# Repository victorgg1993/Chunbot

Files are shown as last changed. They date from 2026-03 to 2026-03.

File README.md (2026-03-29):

# 春 Bot

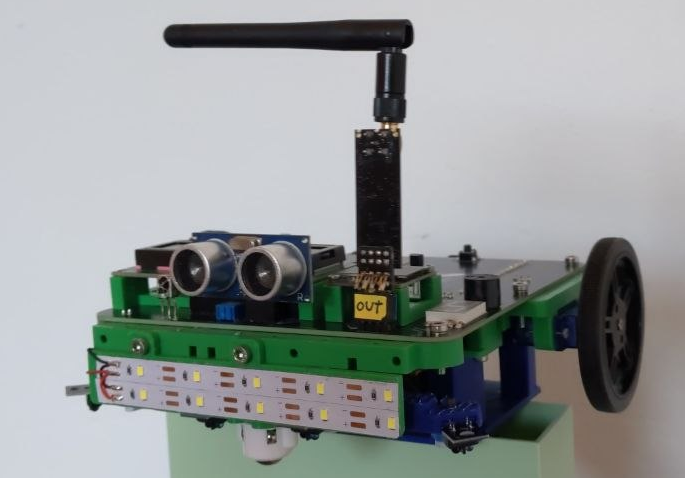
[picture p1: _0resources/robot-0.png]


## Este proyecto tiene dos bloques:

### Mando

- **3D**: modelos 3D del mando
- **Codigo**: Ejemplos de código para el mando
- **PCB**: Diseños de la placa

### Robot

- **3D**: modelos 3D del robot
- **Codigo**: Ejemplos de código para el robot
- **PCB**: Diseños de la placa

## Instalación de dispositivos:

En Linux es necesario añadir los dispositivos en una whitelist en _/etc/udev/rules.d_. Se recomienda seguir la instalación oficial ya que las nuevas versiones de la IDE de Arduino lo gestionan de forma automática.

Link: https://docs.arduino.cc/software/ide-v2/tutorials/getting-started/ide-v2-downloading-and-installing/

---

## Instalación de las librerías:

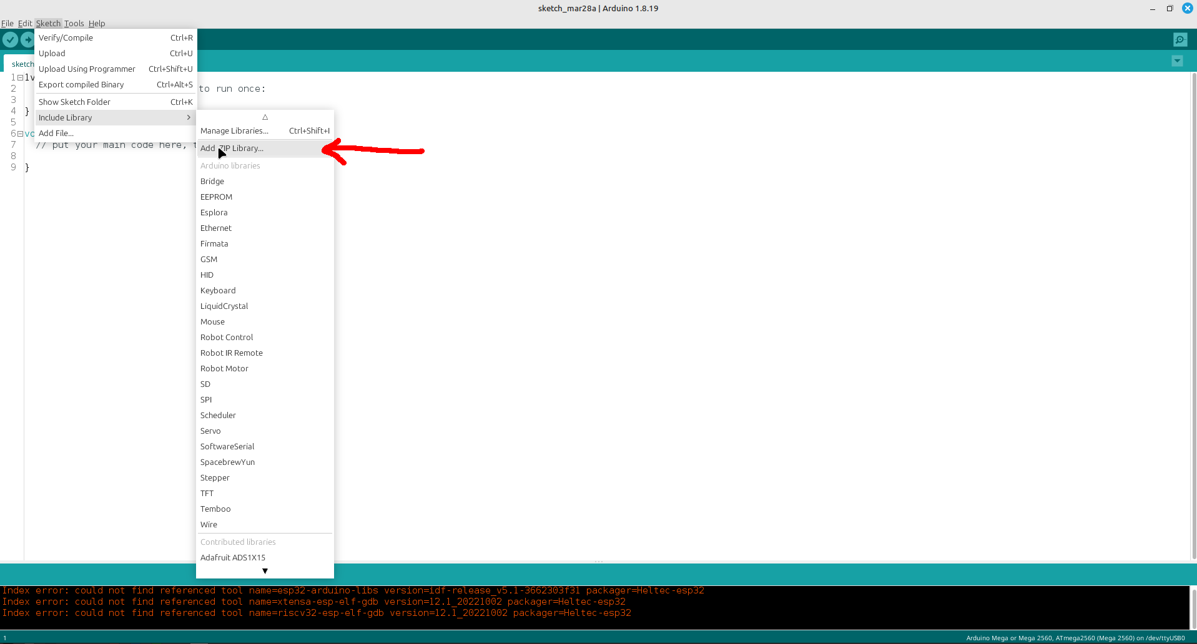
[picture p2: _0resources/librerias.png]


Una vez se abra el menú, cargar las librerías que se encuentran en este proyecto.
La carpeta donde se encuentran las librerías a instalar es "LibreriasArduino".

---

## Elegir microcontrolador:

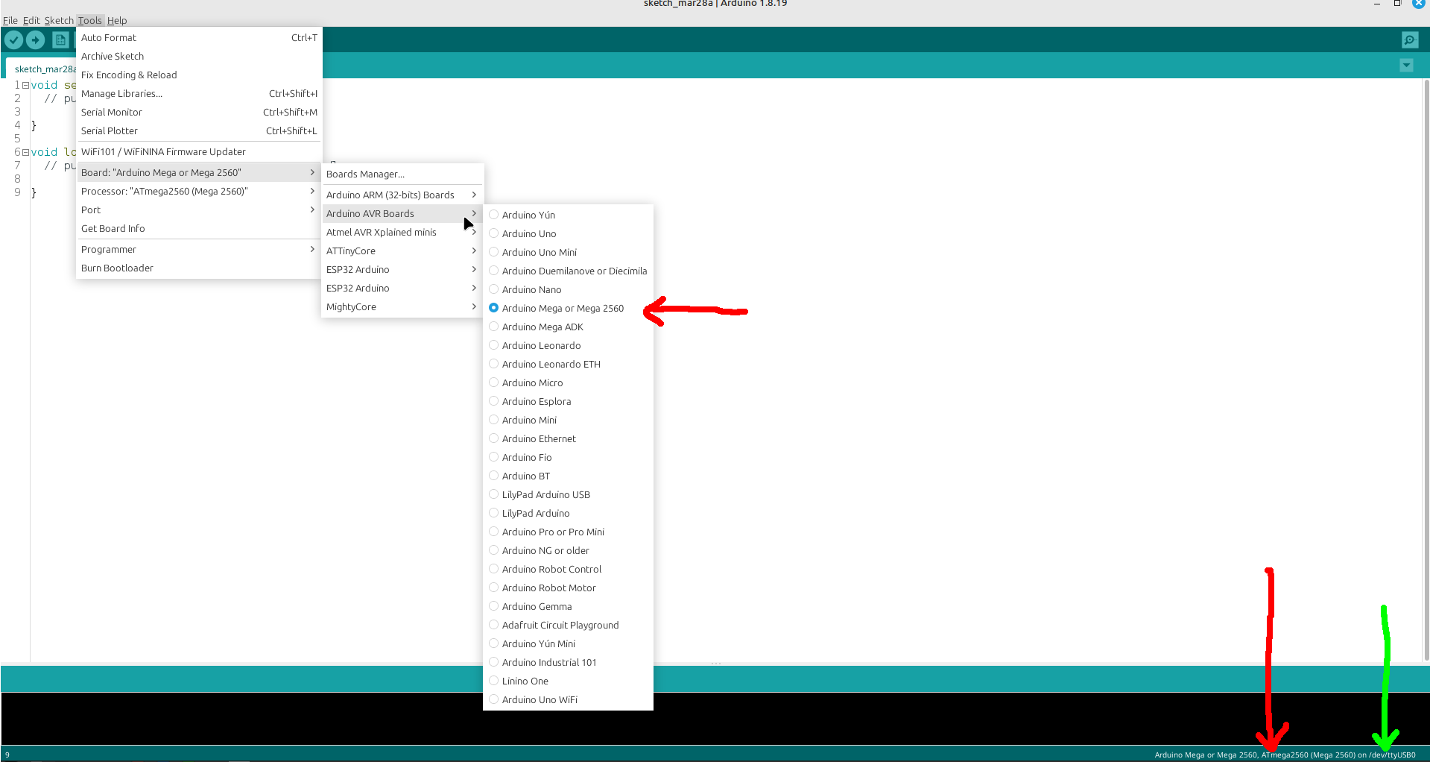
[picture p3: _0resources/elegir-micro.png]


La flecha roja muestra en todo momento qué placa tenemos seleccionada, la verde indica qué puerto USB será usado para programar el microcontrolador.

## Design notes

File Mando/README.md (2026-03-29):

# Mando 春 Bot

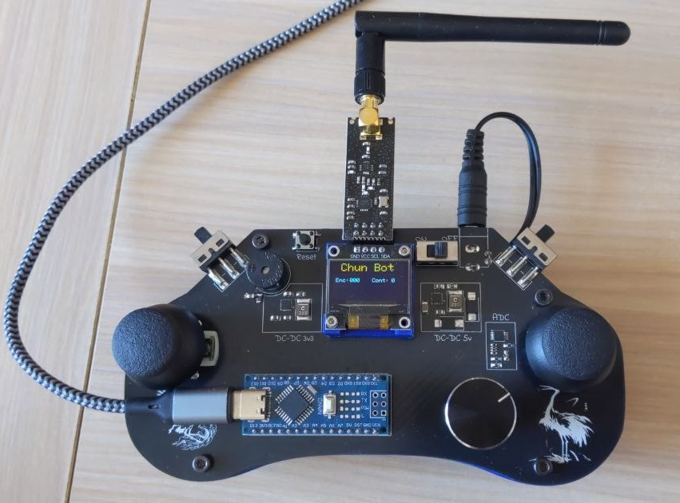
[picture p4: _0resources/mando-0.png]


## Contenido:

- PCB: Diseño de la PCB, tanto esquemáticos como la propia PCB ( Kicad )
- 3D: Modelos 3D ( FreeCAD )
- Codigo: Contiene códigos de ejemplo ( Arduino Nano )

## Pines:

| Uso | Pin | Uso |
| :---: | :-: | :---: |
| Interruptores | D5  | Interruptor lateral derecho |
| Interruptores | D6  | Interruptor lateral izquierdo |
| | | |
| Encoder | D2  | Encoder, pin A. Usa interrupciones |
| Encoder | D3  | Encoder, pin B. Usa interrupciones |
| Encoder | D4  | Pulsador del encoder |
| | | |
| Zumbador | A0  | Pin PWM para el control del zumbador ( buzzer ) |
| | | |
| Joystick | A4  | SDA chip ADC ( analogic to digital converter ) usado para el joystick |
| Joystick | A5  | SCL chip ADC ( analogic to digital converter ) usado para el joystick |
| Joystick | A6  | alert pin del chip ADC ( no implementado ) |
| Joystick | D7  | Pulsador joystick izquierdo |
| Joystick | D8  | Pulsador joystick derecho |
| | | |
| OLED | A4  | SDA, bus I2C de la pantalla OLED. Pin compartido con el joystick |
| OLED | A5  | SCL, bus I2C de la pantalla OLED. Pin compartido con el joystick |
| | | |
| Radio | D13 | Módulo radio NRF24L01, pin SPI SCK |
| Radio | D12 | Módulo radio NRF24L01, pin SPI MISO |
| Radio | D11 | Módulo radio NRF24L01, pin SPI MOSI |
| Radio | D10 | Módulo radio NRF24L01, pin SPI #CNS |
| Radio | D9  | Módulo radio NRF24L01, pin SPI CE |
| | | |

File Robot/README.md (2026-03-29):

# 春 Bot

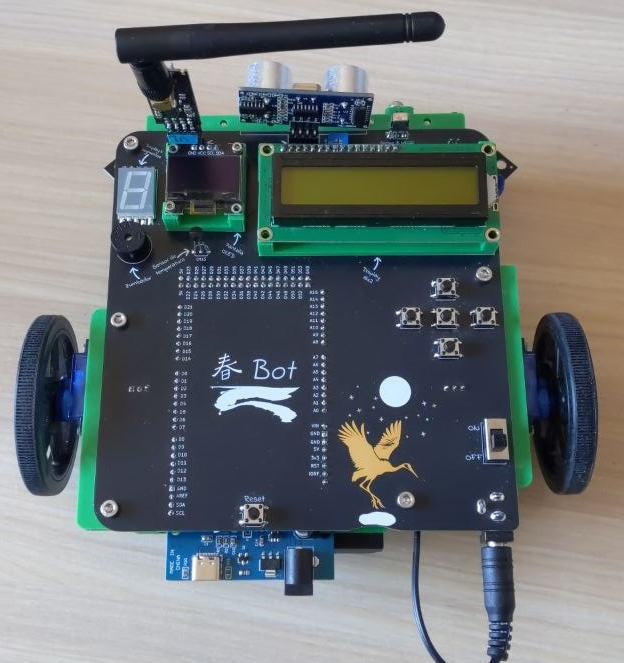
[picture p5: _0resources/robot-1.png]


## Contenido:

- PCB: Diseño de la PCB, tanto esquemáticos como la propia PCB ( Kicad )
- 3D: Modelos 3D ( FreeCAD )
- Codigo: Contiene códigos de ejemplo ( Arduino Mega 2560 )

## Pines:

| Uso | Pin | Uso |
| :---: | :-: | :---: |
| Faros | A14 | Controla un mosfet que enciende y apaga los focos frontales |
| | | |
| Temperatura  | A15 | Sensor de temperatura. Acepta TMP36 y LM35 |
| | | |
|  Pulsadores  | A8  | Pulsador abajo |
|  Pulsadores  | A9  | Pulsador derecha |
|  Pulsadores  | A10 | Pulsador central/ok |
|  Pulsadores  | A11 | Pulsador izquierda |
|  Pulsadores  | A12 | Pulsador arriba |
| | | |
| Radio | D18 | Módulo radio NRF24L01, pin de interrupción. ( no implementado ) |
| Radio | D50 | Módulo radio NRF24L01, pin SPI MISO |
| Radio | D51 | Módulo radio NRF24L01, pin SPI MOSI |
| Radio | D52 | Módulo radio NRF24L01, pin SPI SCK |
| Radio | D53 | Módulo radio NRF24L01, pin SPI #CNS |
| Radio | D43 | Módulo radio NRF24L01, pin SPI CE |
| | | |
| Siguelíneas  | D23 | Sensor izquierdo exterior del seguidor de líneas |
| Siguelíneas  | D41 | Sensor izquierdo interior del seguidor de líneas |
| Siguelíneas  | D42 | Sensor derecho exterior del seguidor de líneas |
| Siguelíneas  | D45 | Sensor derecho interior del seguidor de líneas |
| | | |
| Display16x2  | D33 | Data 4 ( bus de datos ) |
| Display16x2  | D35 | Data 5 ( bus de datos ) |
| Display16x2  | D37 | Data 6 ( bus de datos ) |
| Display16x2  | D39 | Data 7 ( bus de datos ) |
| Display16x2  | D31 | Enable |
| Display16x2  | D29 | RS |
| Display16x2  | D27 | Controla un mosfet que enciende y apaga la luz del display |
| | | |
| Display7seg  | D17 | Segmento A |
| Display7seg  | D25 | Segmento B |
| Display7seg  | D16 | Segmento C |
| Display7seg  | D15 | Segmento D |
| Display7seg  | D14 | Segmento E |
| Display7seg  | D22 | Segmento F |
| Display7seg  | D24 | Segmento G |
| | | |
| OLED | D20 | SDA, bus I2C de la pantalla OLED |
| OLED | D21 | SCL, bus I2C de la pantalla OLED |
| | | |
| Servos | D8  | Servo izquierdo. Usa PWM para su control |
| Servos | D12 | Servo derecho. Usa PWM para su control |
| Servos | D6  | Servo extra 1. Usa PWM para su control |
| Servos | D7  | Servo extra 2. Usa PWM para su control |
| Servos | D9  | Servo extra 3. Usa PWM para su control |
| Servos | D10 | Servo extra 4. Usa PWM para su control |
| Servos | D11 | Servo extra 5. Usa PWM para su control |
| | | |
| Zumbador | D5  | Control vía PWM del zumbador piezoeléctrico |
| | | |
| Mando TV | D4  | Sensor infrarrojo para el mando de TV. Usa el protocolo NEC32 |
| | | |
| Ultrasonidos | D3  | Emite una señal de eco que rebota contra el objeto |
| Ultrasonidos | D2  | Recibe la señal de eco emitida por el otro pin ( usa interrupciones ) |
| | | |

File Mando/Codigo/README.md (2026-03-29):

# Mando 春 Bot

## Ejemplos de código:

- **controlRobot**: Código para controlar el robot vía radiocontrol
- **buzzer**: Suena una melodía por el zumbador
- **encoder**: Imprime por la pantalla OLED el valor del encoder y su pulsador integrado
- **interruptoresLaterales**: Muestra los valores de los interruptores laterales
- **joystick**: Imprime por la pantalla OLED los valores de los joysticks ( eje Y ) y sus pulsadores integrados

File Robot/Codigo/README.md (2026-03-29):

Ejemplos de código:

- **controlRobot**: Código para controlar el robot vía radiocontrol.
- **faros**: Enciende y apaga las luces al pulsar el botón central.
- **display7segmentos**: Incrementa o decrementa el número en función del pulsador derecho o izquierdo.
- **buzzer**: Toca una melodía distinta en función de si se pulsa el botón up, center o down.
- **pulsadores**: muestra el estado de los pulsadores por la pantalla oled.
- **temperatura**: Pinta la temperatura ambiente por el display 16x2. El sensor es el TMP36, aunque aceptaría LM35.
- **ultrasonidos**: Te da la distancia en cm leída del sensor de ultrasonidos por el display 16x2.
- **mandoTV**: Devuelve el código leído del mando de TV por el display 16x2. El número 1 enciende la luz del display, el 0 la apaga.
- **seguidorLineas**: El robot sigue una línea negra sobre fondo blanco ( grosor máximo de la línea, 15mm ).

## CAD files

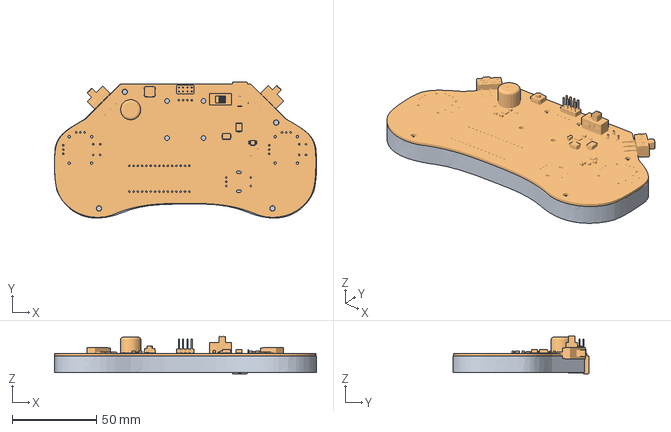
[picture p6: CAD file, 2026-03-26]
Mando/3D/mando.FCStd
155.4 x 80.8 x 22.4 mm
cuerpo
PCB

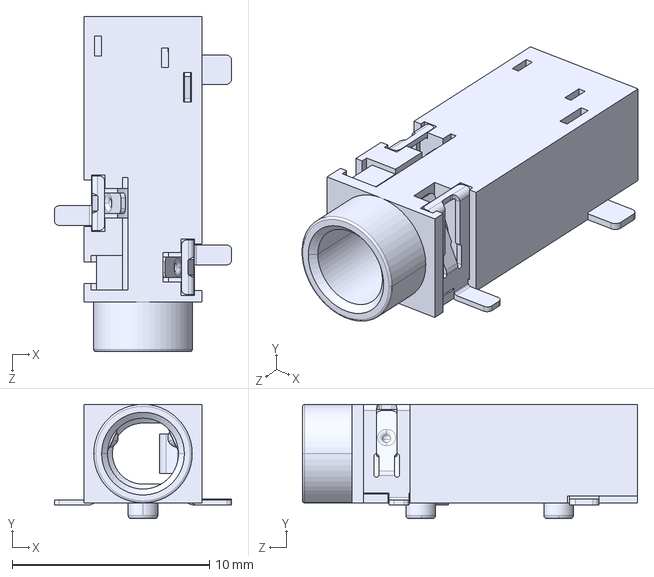
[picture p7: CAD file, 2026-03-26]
Mando/PCB/librerias/3D/SJ-3523-SMT-TR.step
9.00 x 5.80 x 17.0 mm

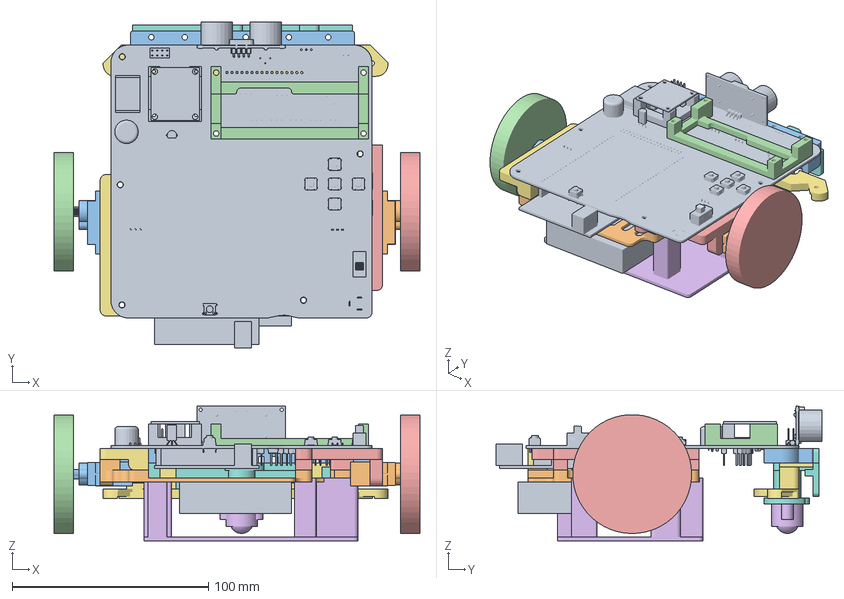
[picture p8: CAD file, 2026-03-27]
Robot/3D/3DChunbot.FCStd
186.3 x 166.0 x 68.6 mm
clip_oled
motor_derecho
motor_izquierdo
rueda_test_izquierdo
rueda_test_derecho
giro-loco
clip_izquierdo_motor
frontal-LED
portapilas
parrilla_pilas
parachoques
clip_16x02
clip_derecho_motor
stand_robot
clip-sensores-ir
base_giro-loco
PCB_ChunBot

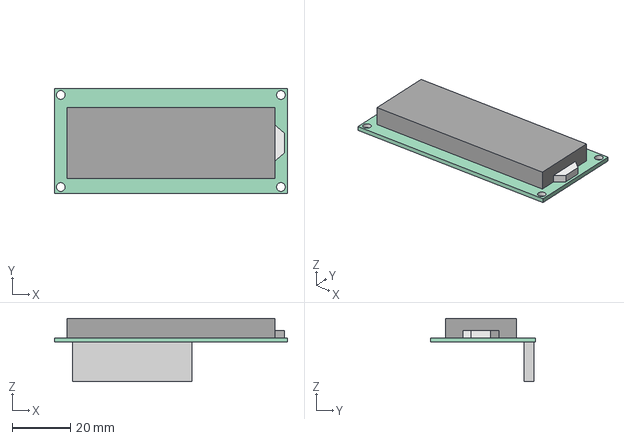
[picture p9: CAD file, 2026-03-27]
Robot/PCB/librerias/3D/display1602.step
80.0 x 36.0 x 21.7 mm

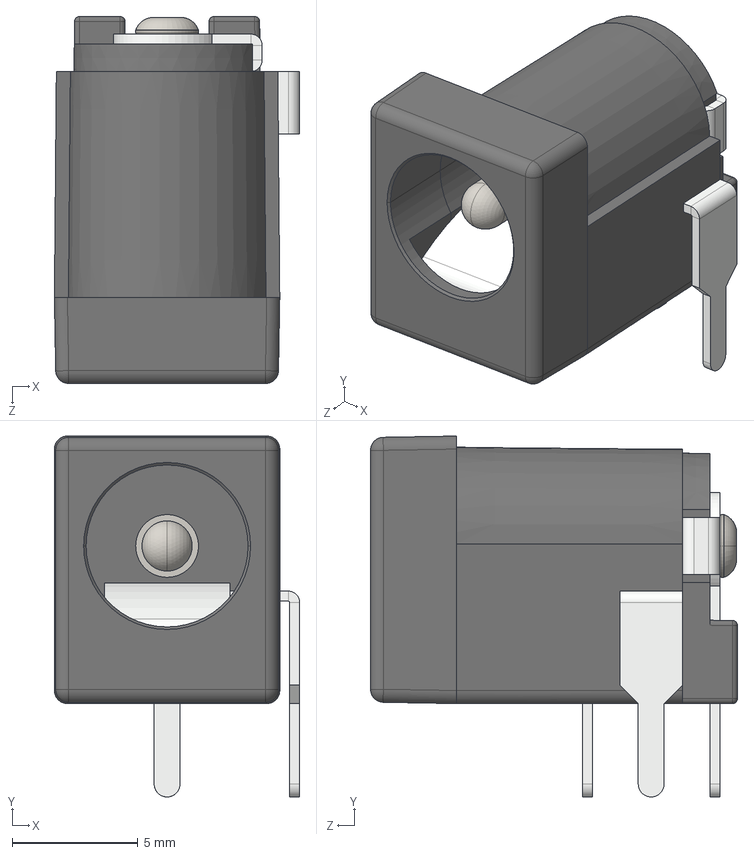
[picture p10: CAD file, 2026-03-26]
Mando/PCB/librerias/3D/PowerJack.STEP
9.77 x 14.4 x 14.6 mm

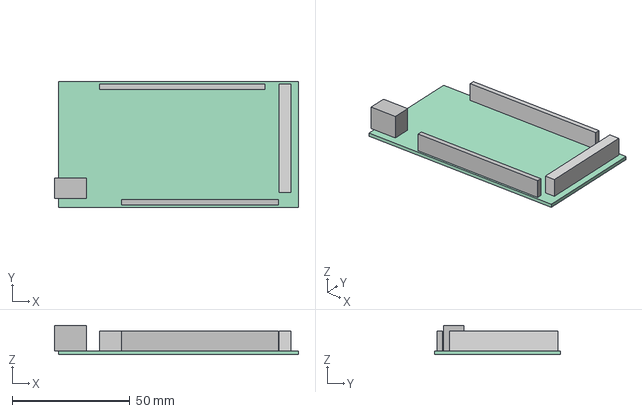
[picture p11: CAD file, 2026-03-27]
Robot/PCB/librerias/3D/Arduino_Mega_2560.step
103.4 x 53.3 x 12.5 mm

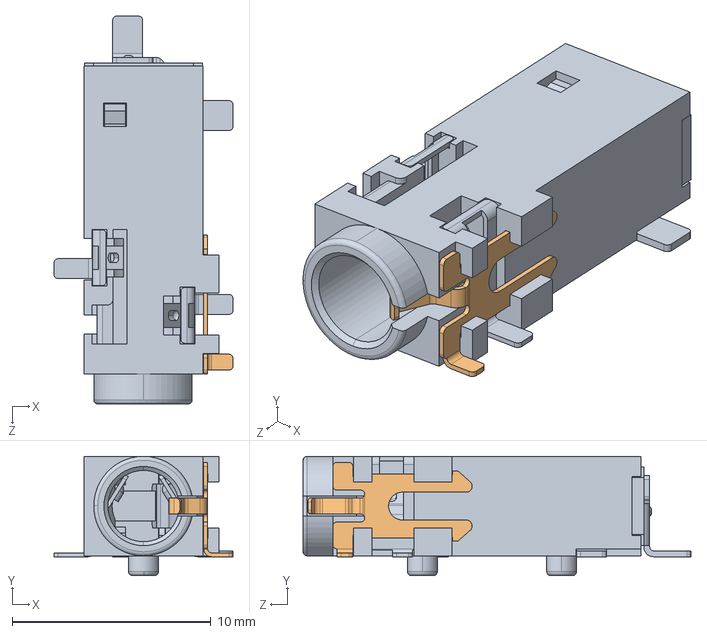
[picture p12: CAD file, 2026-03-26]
Mando/PCB/librerias/3D/SJ-43515TS-SMT-TR.step
9.00 x 6.00 x 19.5 mm

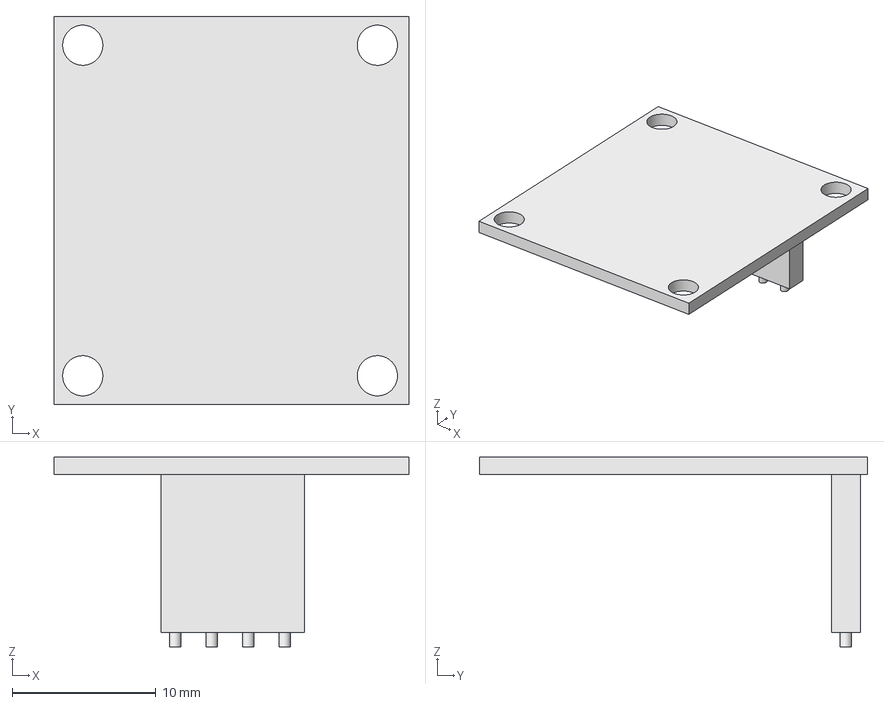
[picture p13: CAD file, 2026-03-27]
Robot/PCB/librerias/3D/oled_096.step
24.7 x 27.0 x 13.2 mm

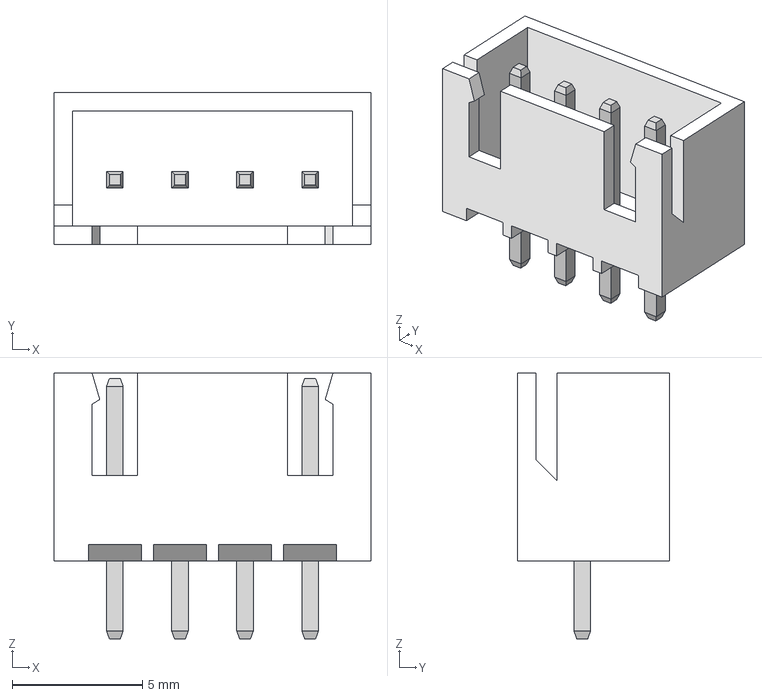
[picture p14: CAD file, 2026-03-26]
Mando/PCB/librerias/3D/JST - XH - Thru - 4Pin - 2.5mm (Genuine).stp
12.2 x 5.84 x 10.2 mm

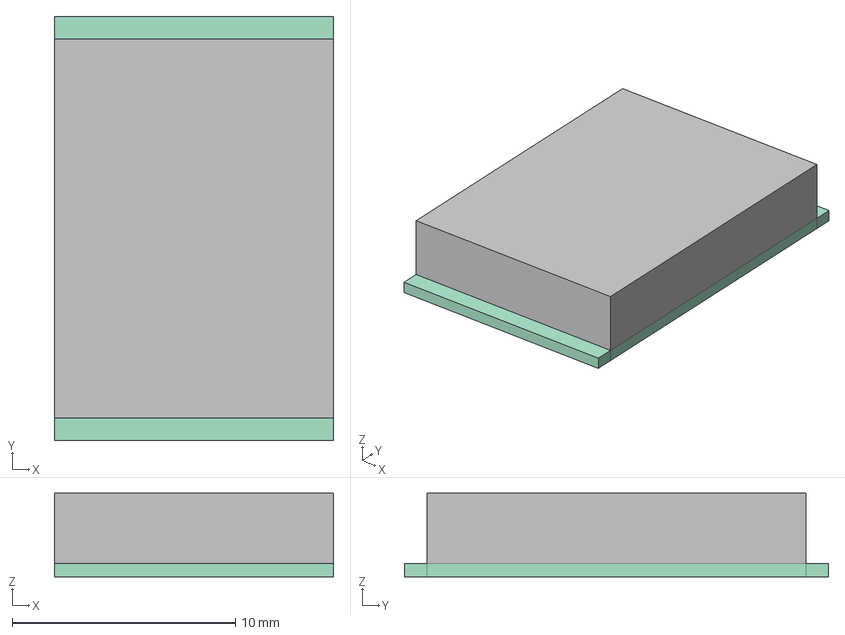
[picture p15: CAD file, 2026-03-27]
Robot/PCB/librerias/3D/7segment.step
12.5 x 19.0 x 3.75 mm

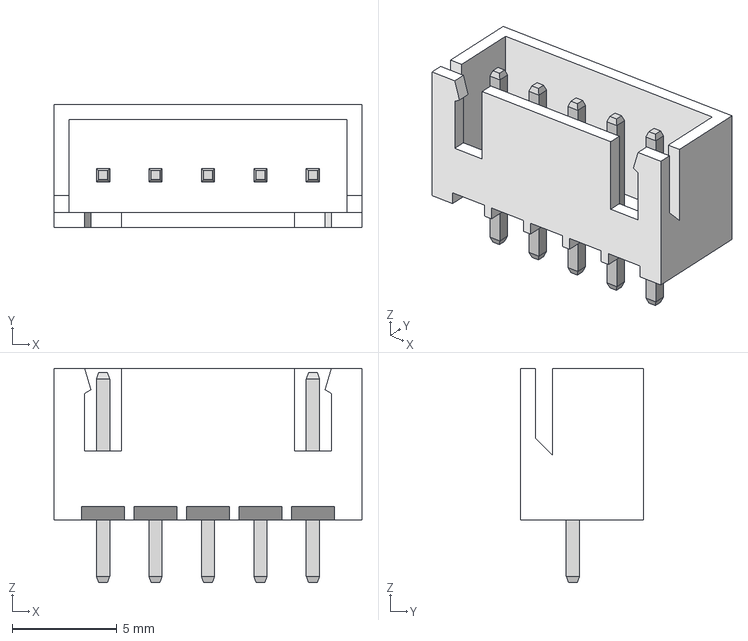
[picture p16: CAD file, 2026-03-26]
Mando/PCB/librerias/3D/JST - XH - Thru - 5Pin - 2.5mm (Genuine).stp
14.7 x 5.84 x 10.2 mm

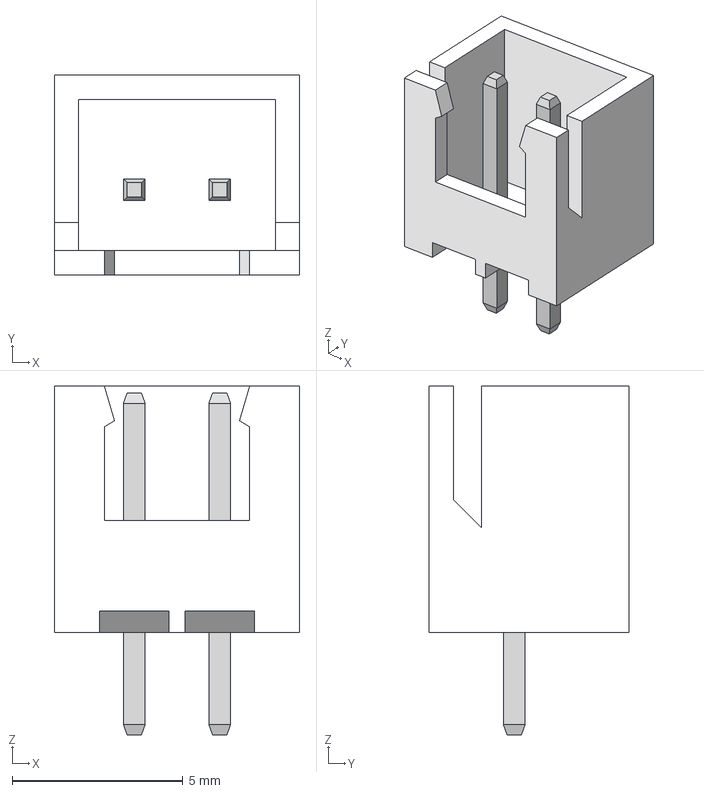
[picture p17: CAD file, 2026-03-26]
Robot/PCB/librerias/3D/JST - XH - Thru - 2Pin - 2.5mm (Genuine).stp
7.17 x 5.84 x 10.2 mm

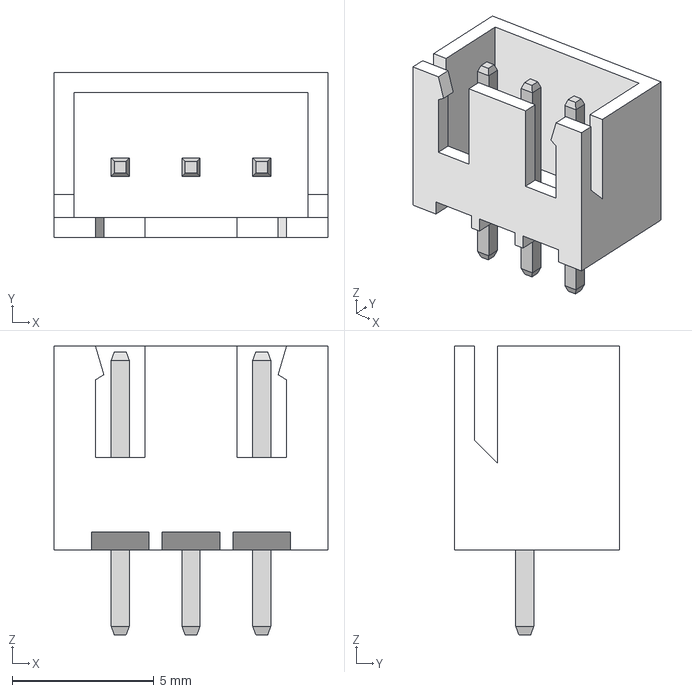
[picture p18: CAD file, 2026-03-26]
Mando/PCB/librerias/3D/JST - XH - Thru - 3Pin - 2.5mm (Genuine).stp
9.67 x 5.84 x 10.2 mm

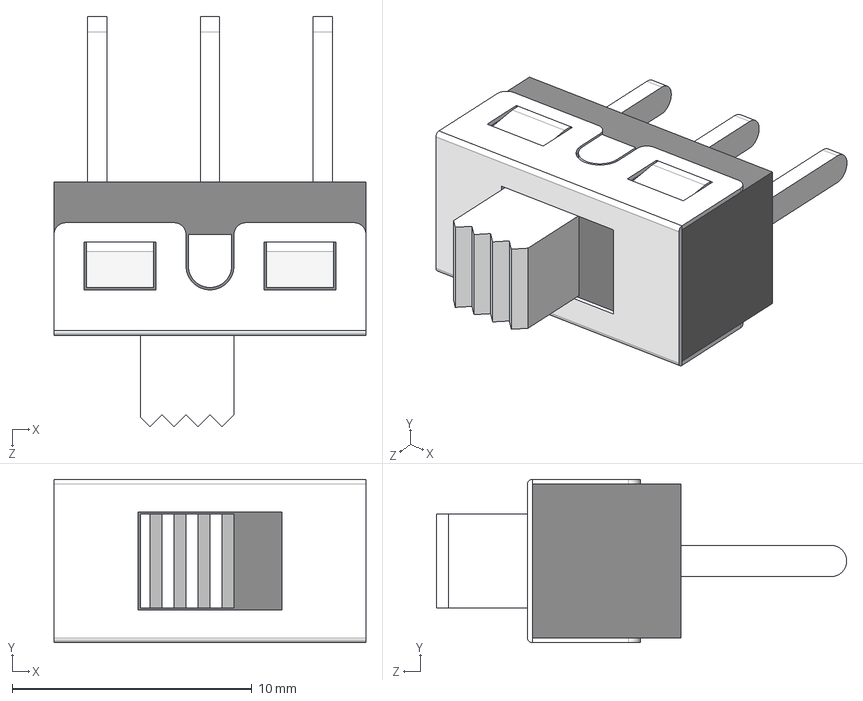
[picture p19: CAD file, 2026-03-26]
Robot/PCB/librerias/3D/SS-12D10L4.STEP
13.0 x 6.80 x 17.1 mm

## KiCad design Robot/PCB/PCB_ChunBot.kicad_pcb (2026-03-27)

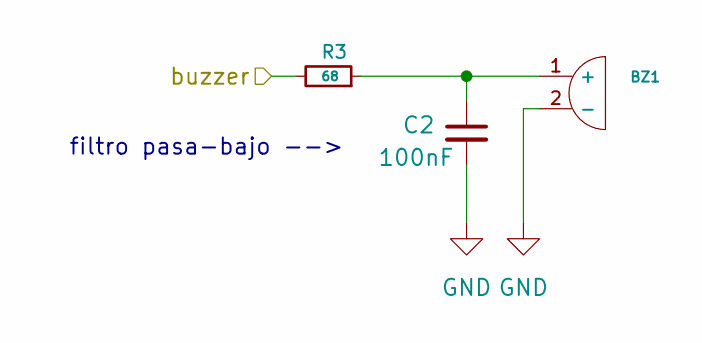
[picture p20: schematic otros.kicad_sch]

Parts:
BZ1: Buzzer_12x9.5RM7.6
C2: 100nF; C_0805_2012Metric_Pad1.18x1.45mm_HandSolder
R3: 68; R_0805_2012Metric

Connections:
GND: BZ1.2 (-), C2.2; also elsewhere on the board
unnamed: BZ1.1 (+), C2.1, R3.1
buzzer: R3.2; also elsewhere on the board

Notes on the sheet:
filtro pasa-bajo -->

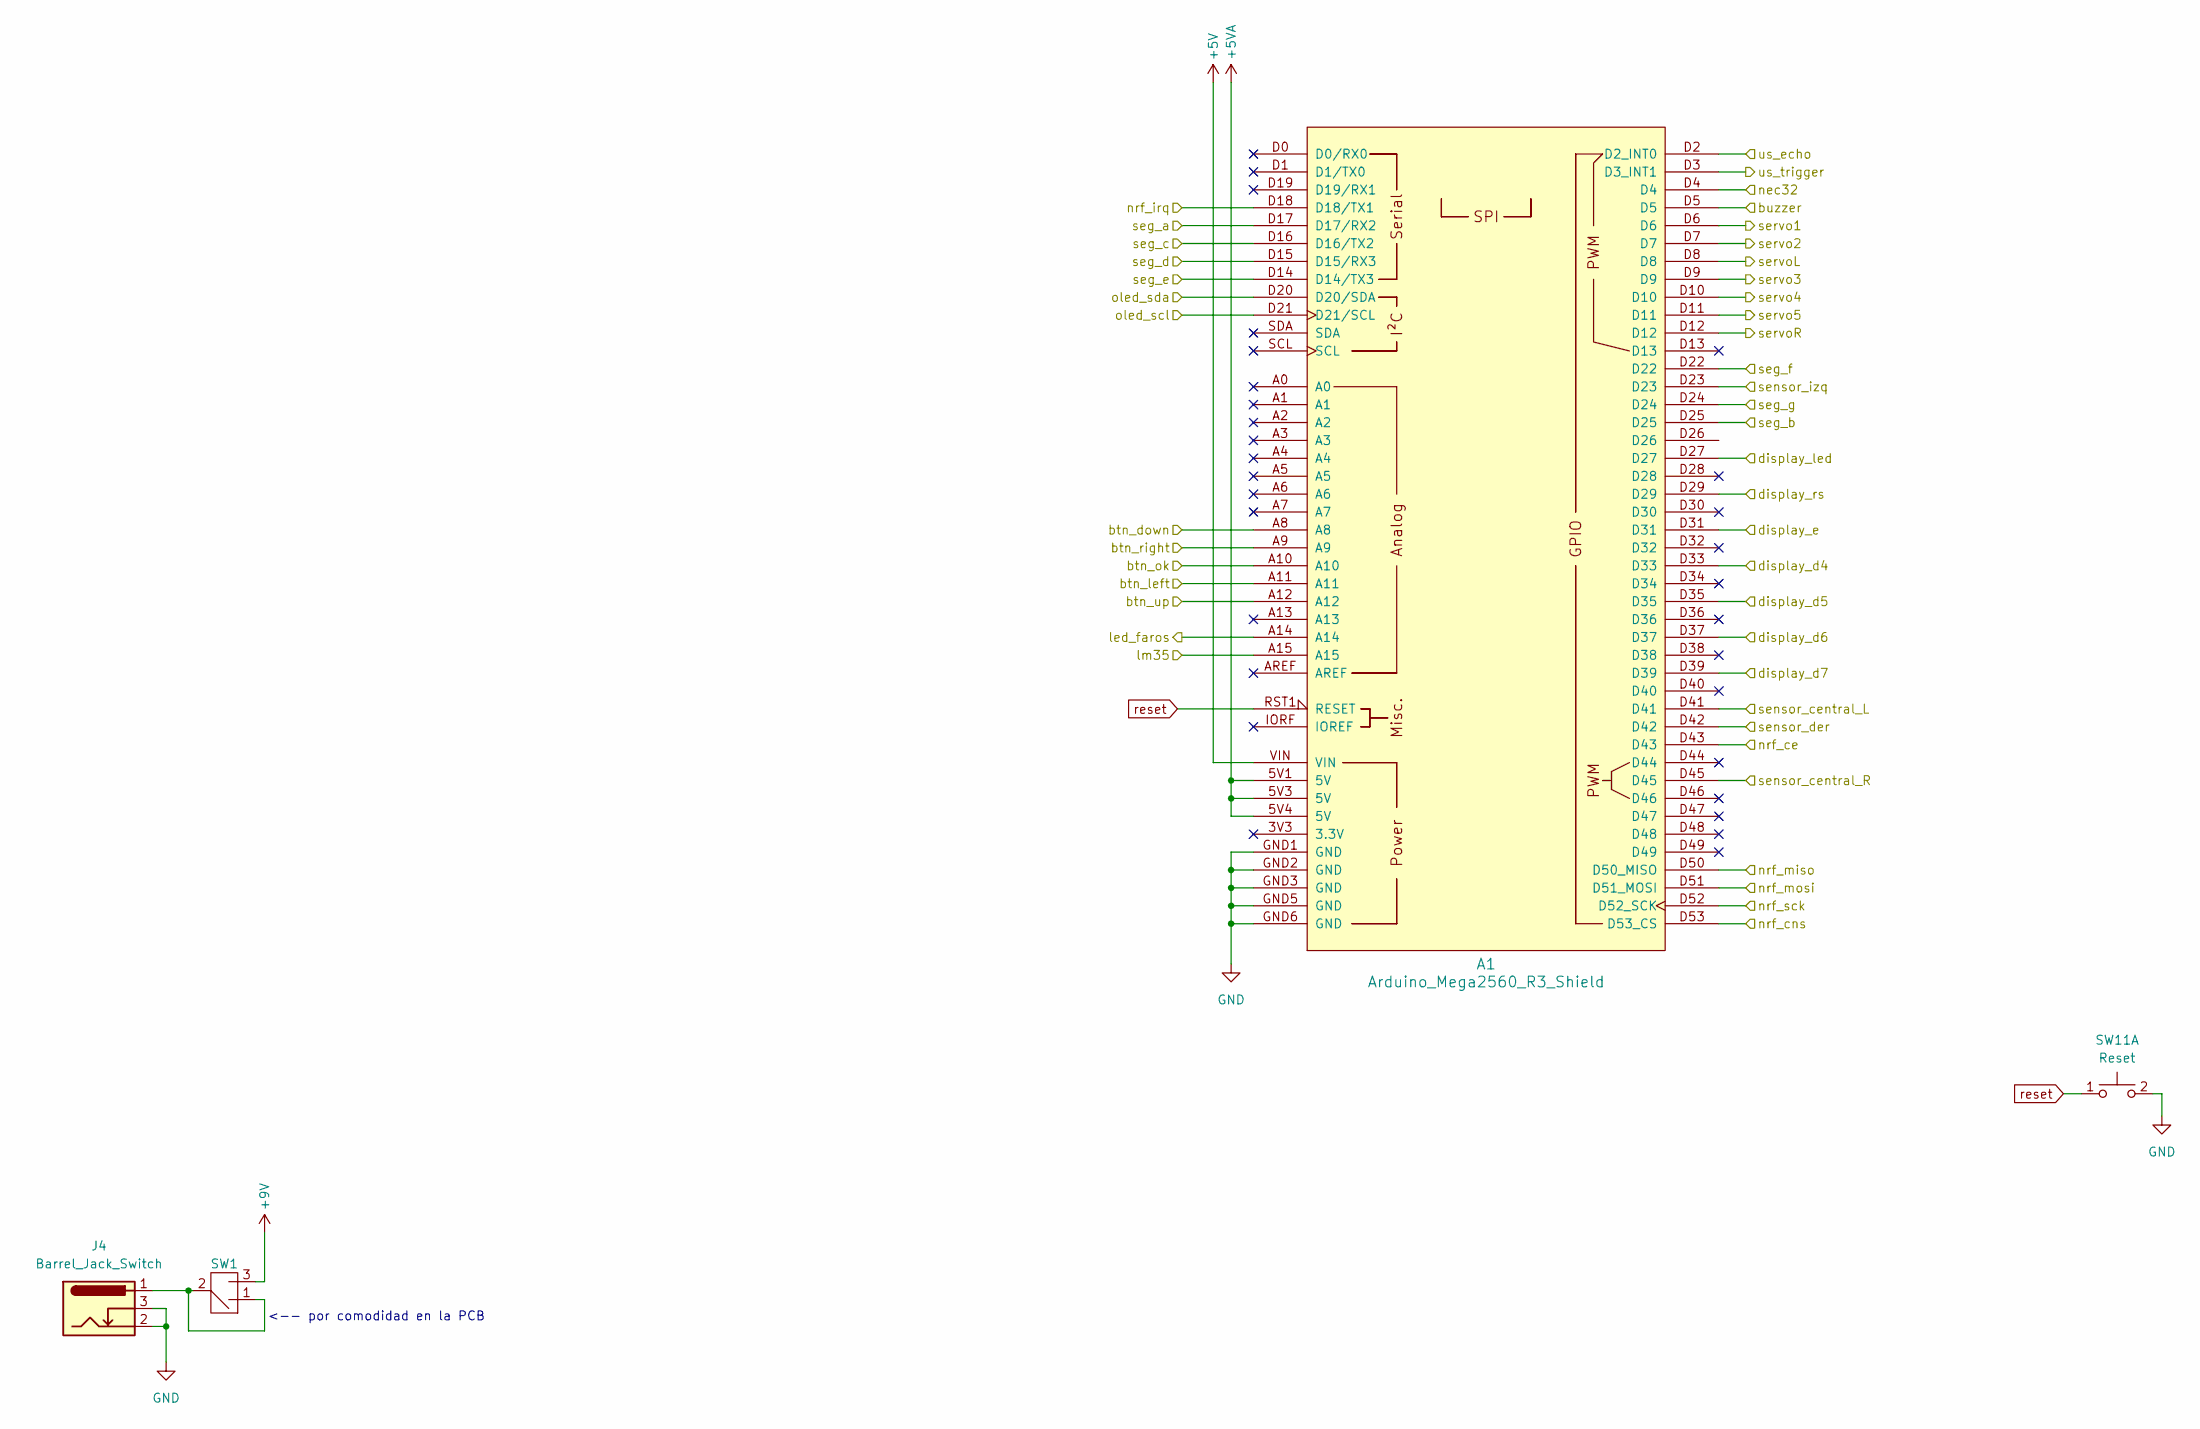
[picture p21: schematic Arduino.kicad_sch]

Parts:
A1: Arduino_Mega2560_R3_Shield
J4: Barrel_Jack_Switch; POWER_JACK_SLOT
SW1: SS12D10
SW11: Reset; SW_PUSH_6mm_H5mm

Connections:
+5V: A1.VIN; also elsewhere on the board
+5VA: A1.5V1 (5V), A1.5V3 (5V), A1.5V4 (5V); also elsewhere on the board
+9V: SW1.3; also elsewhere on the board
GND: A1.GND1 (GND), A1.GND2 (GND), A1.GND3 (GND), A1.GND5 (GND), A1.GND6 (GND), J4.2, J4.3, SW11.2 (D); also elsewhere on the board
unnamed: J4.1, SW1.1, SW1.2
btn_down: A1.A8; also elsewhere on the board
btn_left: A1.A11; also elsewhere on the board
btn_ok: A1.A10; also elsewhere on the board
btn_right: A1.A9; also elsewhere on the board
btn_up: A1.A12; also elsewhere on the board
buzzer: A1.D5; also elsewhere on the board
display_d4: A1.D33; also elsewhere on the board
display_d5: A1.D35; also elsewhere on the board
display_d6: A1.D37; also elsewhere on the board
display_d7: A1.D39; also elsewhere on the board
display_e: A1.D31; also elsewhere on the board
display_led: A1.D27; also elsewhere on the board
display_rs: A1.D29; also elsewhere on the board
led_faro: A1.A14; also elsewhere on the board
lm35: A1.A15; also elsewhere on the board
nec32: A1.D4; also elsewhere on the board
nrf_ce: A1.D43; also elsewhere on the board
nrf_cns: A1.D53 (D53_CS); also elsewhere on the board
nrf_irq: A1.D18 (D18/TX1); also elsewhere on the board
nrf_miso: A1.D50 (D50_MISO); also elsewhere on the board
nrf_mosi: A1.D51 (D51_MOSI); also elsewhere on the board
nrf_sck: A1.D52 (D52_SCK); also elsewhere on the board
oled_scl: A1.D21 (D21/SCL); also elsewhere on the board
oled_sda: A1.D20 (D20/SDA); also elsewhere on the board
reset: A1.RST1 (RESET), SW11.1 (C)
seg_a: A1.D17 (D17/RX2); also elsewhere on the board
seg_b: A1.D25; also elsewhere on the board
seg_c: A1.D16 (D16/TX2); also elsewhere on the board
seg_d: A1.D15 (D15/RX3); also elsewhere on the board
seg_e: A1.D14 (D14/TX3); also elsewhere on the board
seg_f: A1.D22; also elsewhere on the board
seg_g: A1.D24; also elsewhere on the board
sensor_central_L: A1.D41; also elsewhere on the board
sensor_central_R: A1.D45; also elsewhere on the board
sensor_der: A1.D42; also elsewhere on the board
sensor_izq: A1.D23; also elsewhere on the board
servo 1: A1.D6; also elsewhere on the board
servo 2: A1.D7; also elsewhere on the board
servo 3: A1.D9; also elsewhere on the board
servo 4: A1.D10; also elsewhere on the board
servo 5: A1.D11; also elsewhere on the board
servoL: A1.D8; also elsewhere on the board
servoR: A1.D12; also elsewhere on the board
ultrasonidos_echo: A1.D2 (D2_INT0); also elsewhere on the board
ultrasonidos_trigger: A1.D3 (D3_INT1); also elsewhere on the board

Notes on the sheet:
<-- por comodidad en la PCB

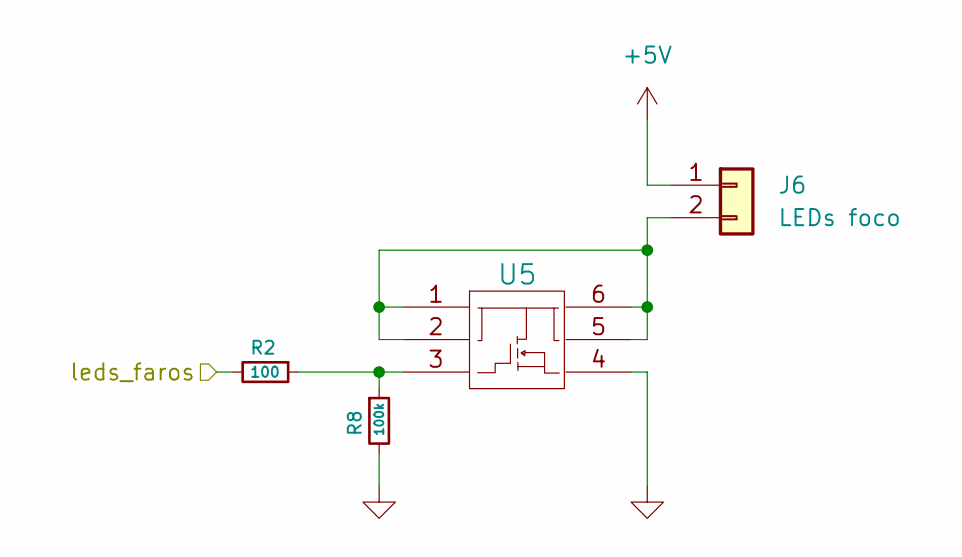
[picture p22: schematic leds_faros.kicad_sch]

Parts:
J6: LEDs foco; XH2.54_2Pin
R2: 100; R_0805_2012Metric
R8: 100k; R_0805_2012Metric
U5: SQ3456BEV; TSOP-6_1.65x3.05mm_P0.95mm

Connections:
+5V: J6.1; also elsewhere on the board
GND: R8.2, U5.4; also elsewhere on the board
unnamed: J6.2, U5.1, U5.2, U5.5, U5.6
unnamed: R2.1, R8.1, U5.3
led_faro: R2.2; also elsewhere on the board

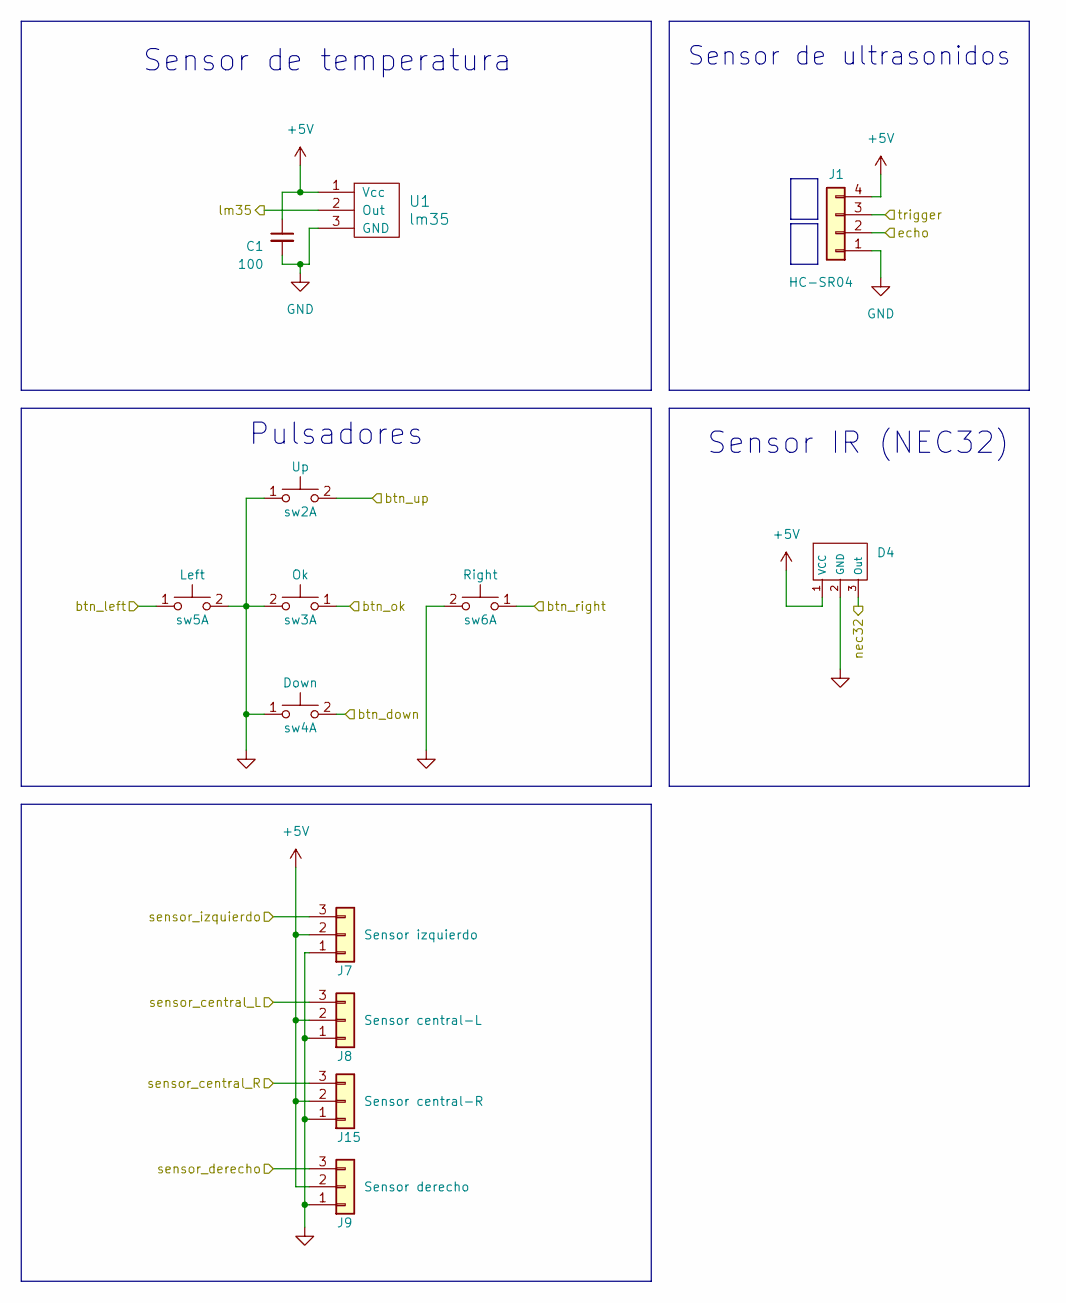
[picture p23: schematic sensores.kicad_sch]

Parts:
C1: 100; C_0805_2012Metric
D4: VS1838
J1: HC-SR04
J7: Sensor izquierdo; PinHeader_1x03_P2.54mm_Vertical
J8: Sensor central-L; PinHeader_1x03_P2.54mm_Vertical
J9: Sensor derecho; PinHeader_1x03_P2.54mm_Vertical
J15: Sensor central-R; PinHeader_1x03_P2.54mm_Vertical
U1: lm35; TO-92L_Inline_Wide
sw2: Up; SW_Push_1P1T_NO_CK_KSC7xxJ
sw3: Ok; SW_Push_1P1T_NO_CK_KSC7xxJ
sw4: Down; SW_Push_1P1T_NO_CK_KSC7xxJ
sw5: Left; SW_Push_1P1T_NO_CK_KSC7xxJ
sw6: Right; SW_Push_1P1T_NO_CK_KSC7xxJ

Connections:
+5V: C1.1, D4.1 (VCC), J1.4, J7.2, J8.2, J9.2, J15.2, U1.1 (Vcc); also elsewhere on the board
GND: C1.2, D4.2 (GND), J1.1, J7.1, J8.1, J9.1, J15.1, U1.3 (GND), sw2.1 (C), sw3.2 (D), sw4.1 (C), sw5.2 (D), sw6.2 (D); also elsewhere on the board
btn_down: sw4.2 (D); also elsewhere on the board
btn_left: sw5.1 (C); also elsewhere on the board
btn_ok: sw3.1 (C); also elsewhere on the board
btn_right: sw6.1 (C); also elsewhere on the board
btn_up: sw2.2 (D); also elsewhere on the board
lm35: U1.2 (Out); also elsewhere on the board
nec32: D4.3 (Out); also elsewhere on the board
sensor_central_L: J8.3; also elsewhere on the board
sensor_central_R: J15.3; also elsewhere on the board
sensor_der: J9.3; also elsewhere on the board
sensor_izq: J7.3; also elsewhere on the board
ultrasonidos_echo: J1.2; also elsewhere on the board
ultrasonidos_trigger: J1.3; also elsewhere on the board

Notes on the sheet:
Sensor IR (NEC32)
Sensor de ultrasonidos
Sensor de temperatura
Pulsadores

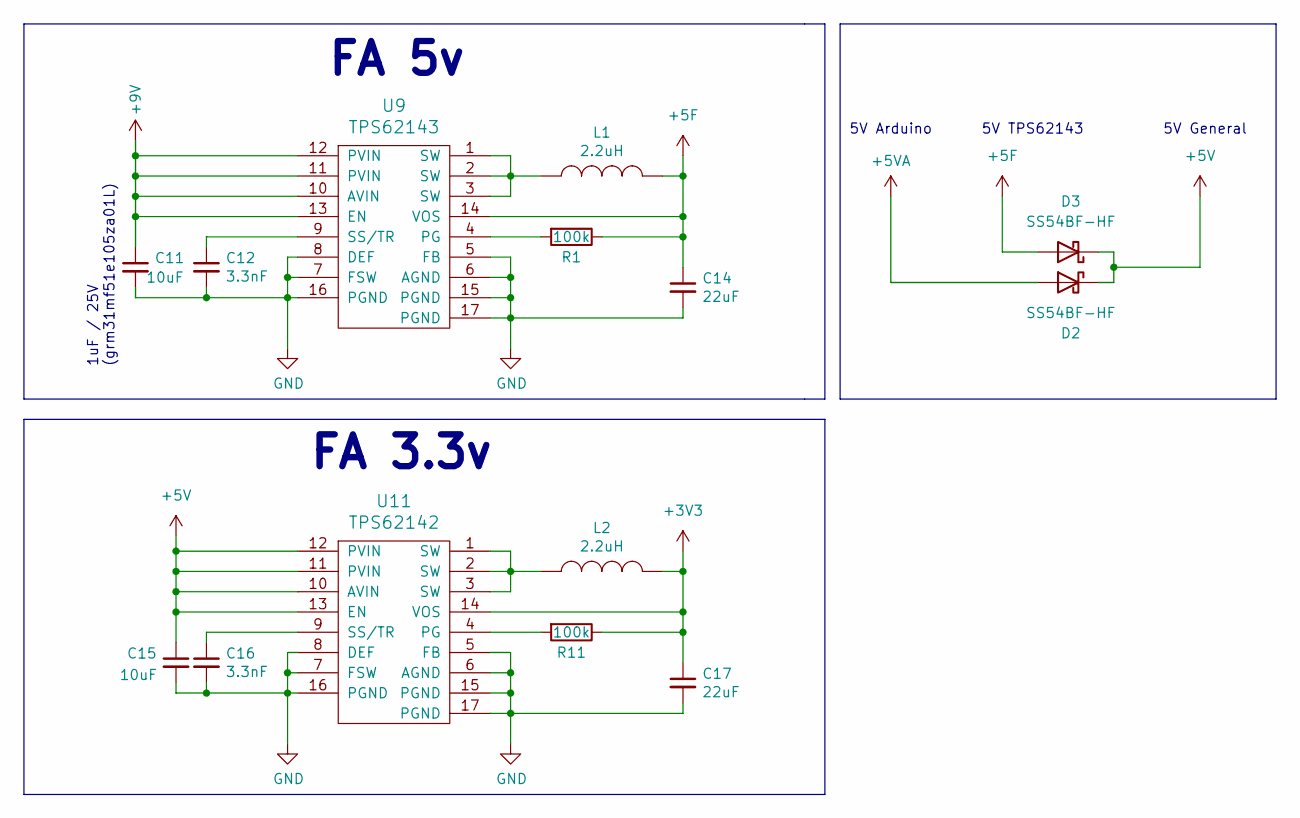
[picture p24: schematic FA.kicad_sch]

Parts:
C11: 10uF; C_1206_3216Metric_Pad1.33x1.80mm_HandSolder
C12, C16: 3.3nF; C_0805_2012Metric_Pad1.18x1.45mm_HandSolder
C14, C17: 22uF; C_0805_2012Metric_Pad1.18x1.45mm_HandSolder
C15: 10uF; C_0805_2012Metric_Pad1.18x1.45mm_HandSolder
D2, D3: SS54BF-HF; D_SMB_Handsoldering
L1, L2: 2.2uH; L_Taiyo-Yuden_NR-50xx_HandSoldering
R1, R11: 100k; R_0805_2012Metric_Pad1.20x1.40mm_HandSolder
U9: TPS62143; QFN-16-1EP_3x3mm_P0.5mm_EP1.7x1.7mm
U11: TPS62142; QFN-16-1EP_3x3mm_P0.5mm_EP1.7x1.7mm

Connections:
+3V3: C17.1, L2.2, R11.1, U11.14 (VOS); also elsewhere on the board
+5F: C14.1, D3.2 (A), L1.2, R1.1, U9.14 (VOS)
+5V: C15.1, D2.1 (K), D3.1 (K), U11.10 (AVIN), U11.11 (PVIN), U11.12 (PVIN), U11.13 (EN); also elsewhere on the board
+5VA: D2.2 (A); also elsewhere on the board
+9V: C11.1, U9.10 (AVIN), U9.11 (PVIN), U9.12 (PVIN), U9.13 (EN); also elsewhere on the board
GND: C11.2, C12.2, C14.2, C15.2, C16.2, C17.2, U9.5 (FB), U9.6 (AGND), U9.7 (FSW), U9.8 (DEF), U9.15 (PGND), U9.16 (PGND), U9.17 (PGND), U11.5 (FB), U11.6 (AGND), U11.7 (FSW), U11.8 (DEF), U11.15 (PGND), U11.16 (PGND), U11.17 (PGND); also elsewhere on the board
unnamed: L1.1, U9.1 (SW), U9.2 (SW), U9.3 (SW)
unnamed: L2.1, U11.1 (SW), U11.2 (SW), U11.3 (SW)
unnamed: R1.2, U9.4 (PG)
unnamed: C12.1, U9.9 (SS/TR)
unnamed: R11.2, U11.4 (PG)
unnamed: C16.1, U11.9 (SS/TR)

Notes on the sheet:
5V General
5V TPS62143
FA 5v
1uF / 25V (grm31mf51e105za01L)
5V Arduino
FA 3.3v

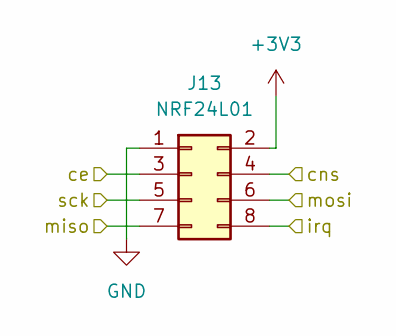
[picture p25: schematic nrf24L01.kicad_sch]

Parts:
J13: NRF24L01; PinHeader_2x04_P2.54mm_Vertical

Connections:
+3V3: J13.2; also elsewhere on the board
GND: J13.1; also elsewhere on the board
nrf_ce: J13.3; also elsewhere on the board
nrf_cns: J13.4; also elsewhere on the board
nrf_irq: J13.8; also elsewhere on the board
nrf_miso: J13.7; also elsewhere on the board
nrf_mosi: J13.6; also elsewhere on the board
nrf_sck: J13.5; also elsewhere on the board

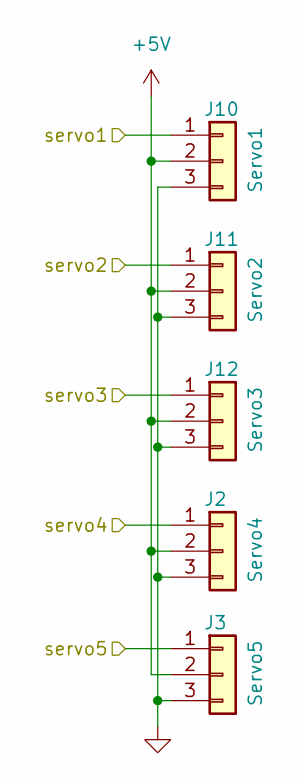
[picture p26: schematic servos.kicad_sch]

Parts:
J2: Servo4; PinHeader_1x03_P2.54mm_Vertical
J3: Servo5; PinHeader_1x03_P2.54mm_Vertical
J10: Servo1; PinHeader_1x03_P2.54mm_Vertical
J11: Servo2; PinHeader_1x03_P2.54mm_Vertical
J12: Servo3; PinHeader_1x03_P2.54mm_Vertical

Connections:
+5V: J2.2, J3.2, J10.2, J11.2, J12.2; also elsewhere on the board
GND: J2.3, J3.3, J10.3, J11.3, J12.3; also elsewhere on the board
servo 1: J10.1; also elsewhere on the board
servo 2: J11.1; also elsewhere on the board
servo 3: J12.1; also elsewhere on the board
servo 4: J2.1; also elsewhere on the board
servo 5: J3.1; also elsewhere on the board

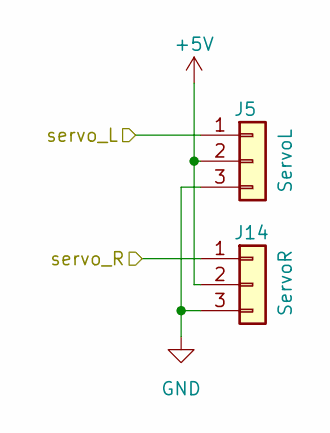
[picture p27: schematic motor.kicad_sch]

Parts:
J5: ServoL; PinHeader_1x03_P2.54mm_Horizontal
J14: ServoR; PinHeader_1x03_P2.54mm_Horizontal

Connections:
+5V: J5.2, J14.2; also elsewhere on the board
GND: J5.3, J14.3; also elsewhere on the board
servoL: J5.1; also elsewhere on the board
servoR: J14.1; also elsewhere on the board

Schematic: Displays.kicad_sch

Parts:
D1: SS511UBWA
DS1: WC1602A
R6: 200; R_0805_2012Metric
R7: 100; R_0805_2012Metric
R9: 100k; R_0805_2012Metric
R10: 150; R_0805_2012Metric
RV1: R_Potentiometer; 3362P
U2: OLED096
U3: SQ3456BEV; TSOP-6_1.65x3.05mm_P0.95mm

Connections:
+5V: DS1.2 (VDD), DS1.15 (LED(+)), RV1.1, U2.2 (VCC); also elsewhere on the board
GND: DS1.1 (VSS), DS1.5 (R/W), R9.2, R10.2, RV1.3, U2.1 (GND), U3.4; also elsewhere on the board
unnamed: D1.3 (K), D1.8 (K), R10.1
unnamed: DS1.16 (LED(-)), R6.1
unnamed: DS1.3 (VO), RV1.2
unnamed: R6.2, U3.1, U3.2, U3.5, U3.6
unnamed: R7.1, R9.1, U3.3
display_d4: DS1.11 (D4); also elsewhere on the board
display_d5: DS1.12 (D5); also elsewhere on the board
display_d6: DS1.13 (D6); also elsewhere on the board
display_d7: DS1.14 (D7); also elsewhere on the board
display_e: DS1.6 (E); also elsewhere on the board
display_led: R7.2; also elsewhere on the board
display_rs: DS1.4 (RS); also elsewhere on the board
oled_scl: U2.3 (SCL); also elsewhere on the board
oled_sda: U2.4 (SDA); also elsewhere on the board
seg_a: D1.7 (a); also elsewhere on the board
seg_b: D1.6 (b); also elsewhere on the board
seg_c: D1.4 (c); also elsewhere on the board
seg_d: D1.2 (d); also elsewhere on the board
seg_e: D1.1 (e); also elsewhere on the board
seg_f: D1.9 (f); also elsewhere on the board
seg_g: D1.10 (g); also elsewhere on the board

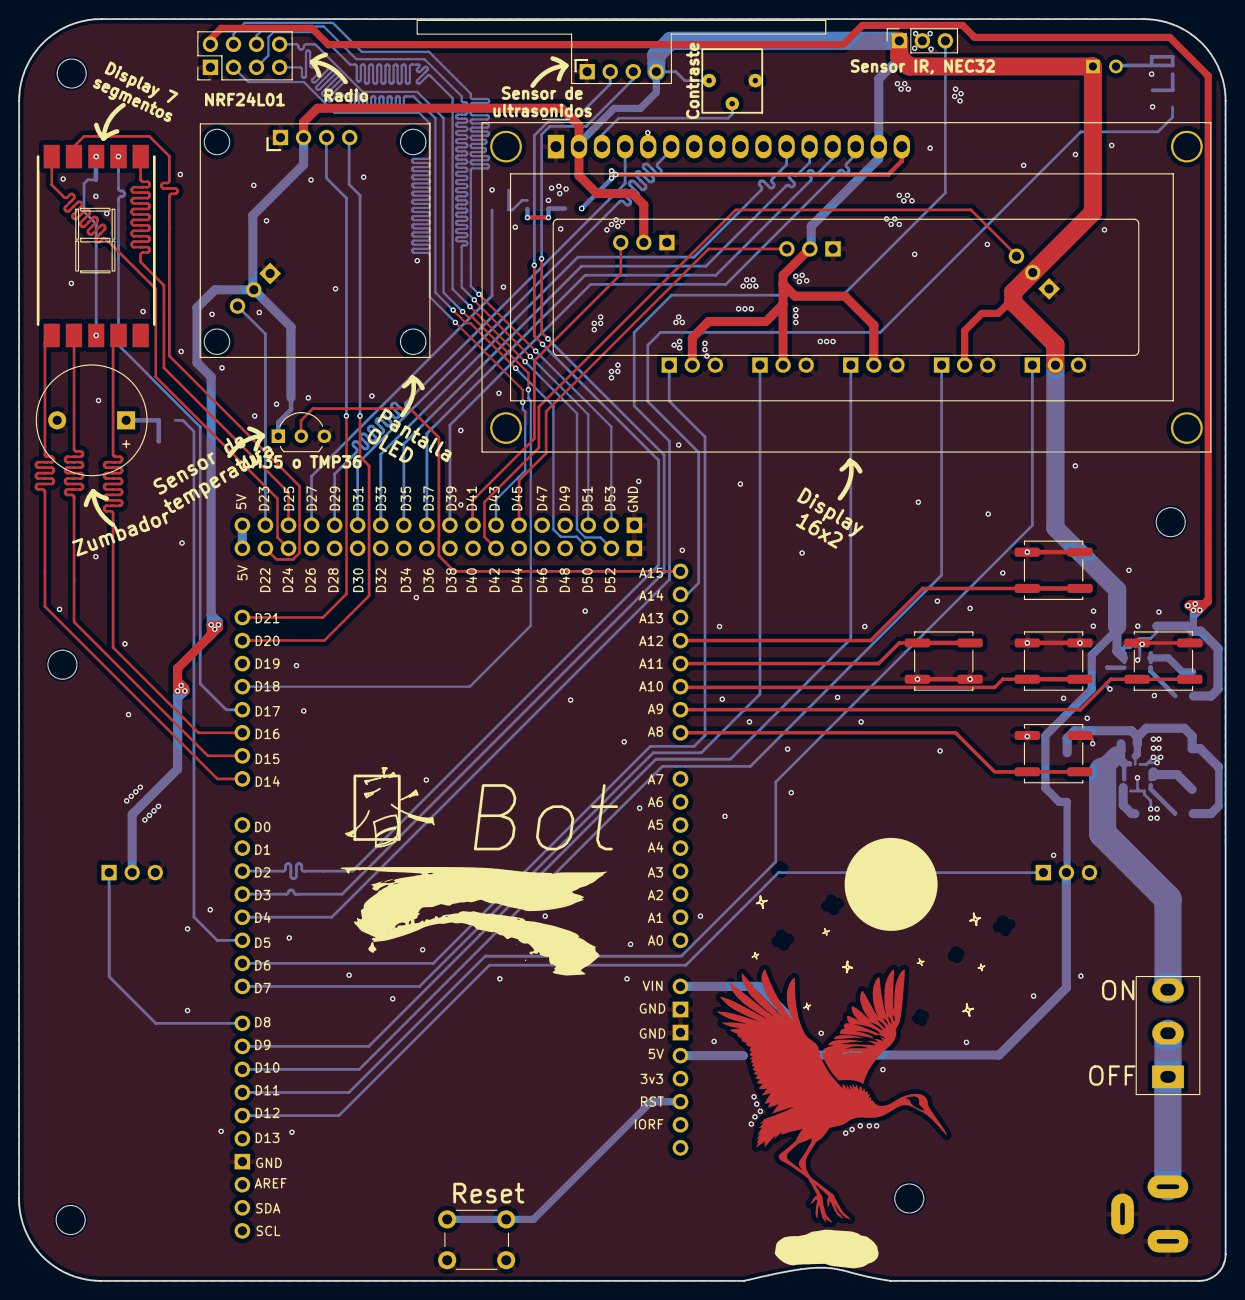
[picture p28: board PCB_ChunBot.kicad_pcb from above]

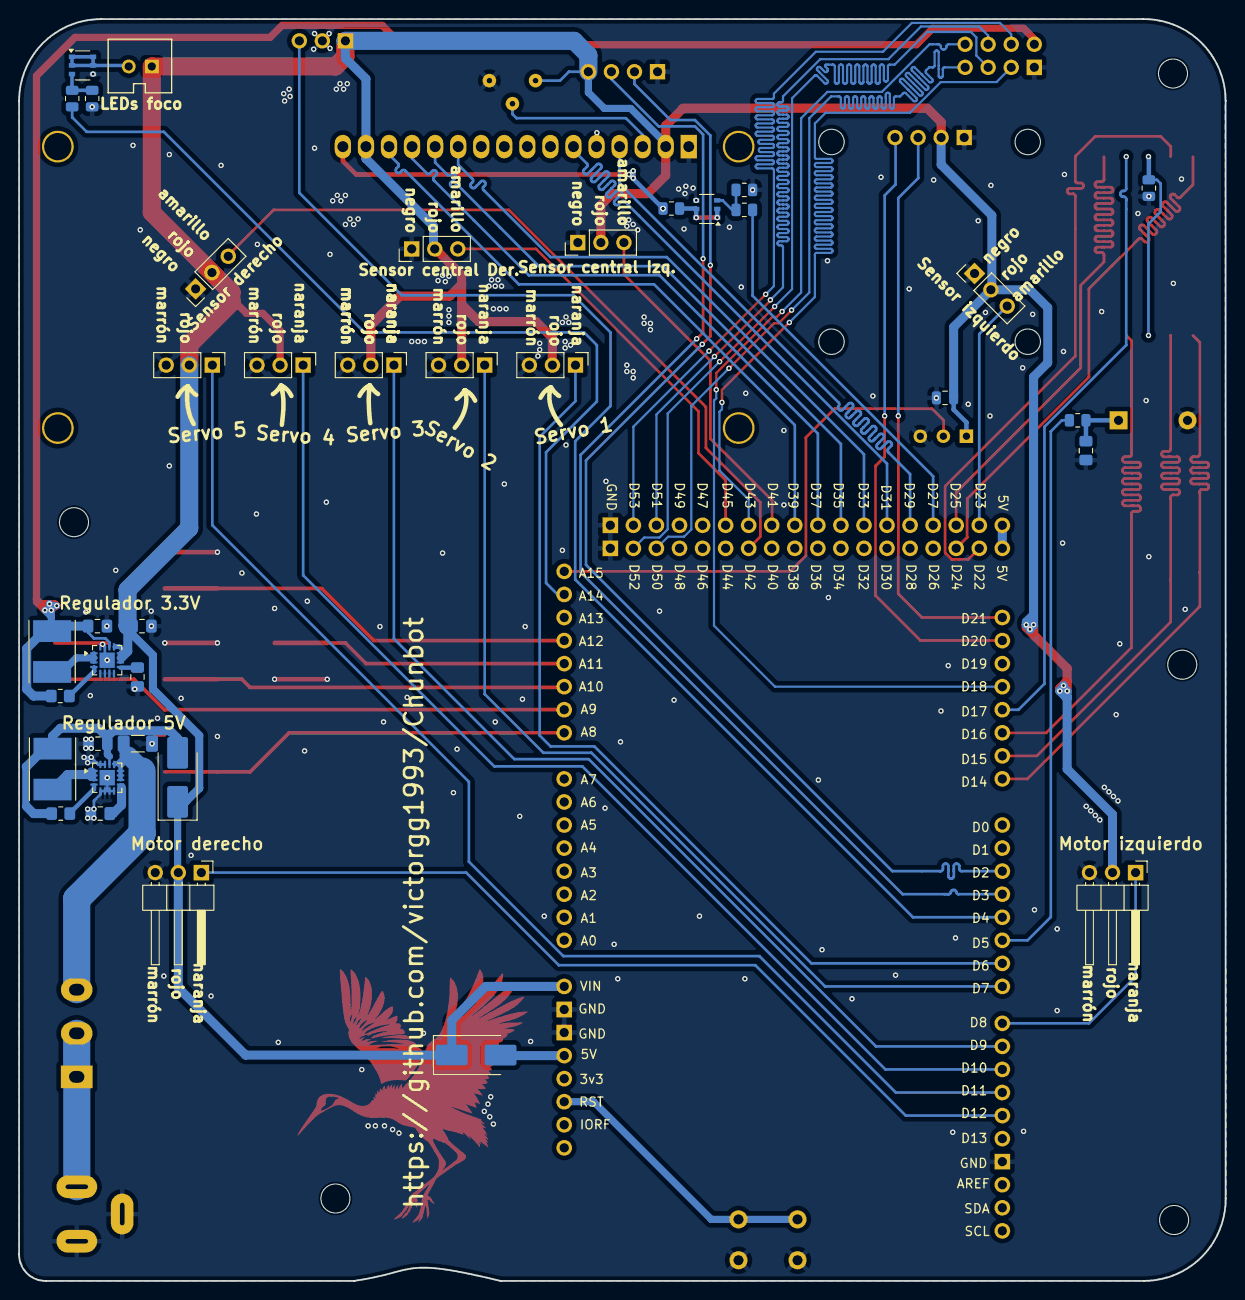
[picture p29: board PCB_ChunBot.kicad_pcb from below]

Board: 2 copper layers, 132.9 x 139.0 mm, 55 parts (38 on the bottom side), 66 nets.

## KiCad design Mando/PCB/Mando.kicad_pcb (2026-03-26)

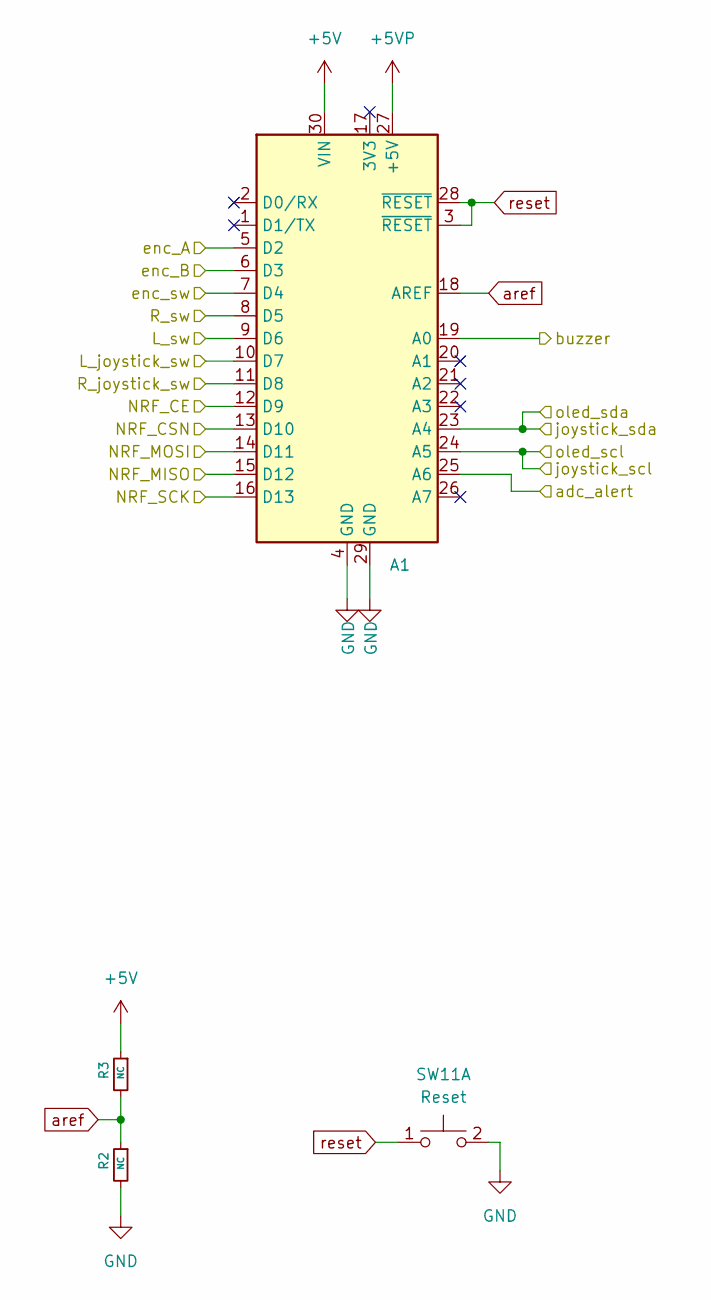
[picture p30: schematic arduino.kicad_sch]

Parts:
A1: Arduino_Nano_v3.x; Arduino_Nano
R2, R3: NC; R_0805_2012Metric
SW11: Reset; SW_Push_1P1T_NO_CK_KSC7xxJ

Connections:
+5V: A1.30 (VIN), R3.1; also elsewhere on the board
+5VP: A1.27 (+5V); also elsewhere on the board
GND: A1.4 (GND), A1.29 (GND), R2.2, SW11.2 (D); also elsewhere on the board
L_joy_sw: A1.10 (D7); also elsewhere on the board
L_switch: A1.9 (D6); also elsewhere on the board
adc_alert: A1.25 (A6); also elsewhere on the board
aref: A1.18 (AREF), R2.1, R3.2
buzzer: A1.19 (A0); also elsewhere on the board
enc_A: A1.5 (D2); also elsewhere on the board
enc_B: A1.6 (D3); also elsewhere on the board
enc_sw: A1.7 (D4); also elsewhere on the board
nrf_ce: A1.12 (D9); also elsewhere on the board
nrf_cns: A1.13 (D10); also elsewhere on the board
nrf_miso: A1.15 (D12); also elsewhere on the board
nrf_mosi: A1.14 (D11); also elsewhere on the board
nrf_sck: A1.16 (D13); also elsewhere on the board
oled_scl: A1.24 (A5); also elsewhere on the board
oled_sda: A1.23 (A4); also elsewhere on the board
r_joy_sw: A1.11 (D8); also elsewhere on the board
r_switch: A1.8 (D5); also elsewhere on the board
reset: A1.3 (~RESET), A1.28 (~RESET), SW11.1 (C)

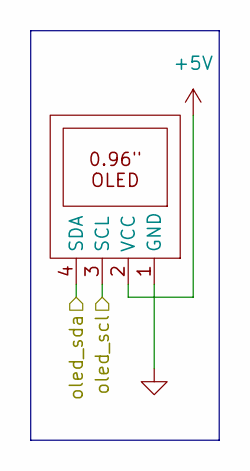
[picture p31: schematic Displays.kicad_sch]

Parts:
U3: OLED096

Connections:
+5V: U3.2 (VCC); also elsewhere on the board
GND: U3.1 (GND); also elsewhere on the board
oled_scl: U3.3 (SCL); also elsewhere on the board
oled_sda: U3.4 (SDA); also elsewhere on the board


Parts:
C1, C2: C_Small; C_0805_2012Metric_Pad1.18x1.45mm_HandSolder
L3, L4: L_Small; L_0805_2012Metric_Pad1.05x1.20mm_HandSolder
Ra1: array_resistors_04; R_Array_Convex_4x0612
SW2, SW3: SS12D10_SMD
U1, U2: KY-023
U5: ADS1115IDGS; TSSOP-10_3x3mm_P0.5mm

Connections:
+5V: C2.1, L4.1, SW2.1, SW3.3, U1.3, U1.7, U2.3, U2.7; also elsewhere on the board
GND: C2.2, L3.2, SW2.3, SW3.1, U1.1, U1.5, U1.6 (GND), U1.9, U2.1, U2.5, U2.6 (GND), U2.9; also elsewhere on the board
L_eje_x: U1.2, U5.4 (AIN0)
L_eje_y: U1.8, U5.5 (AIN1)
L_joy_sw: U1.4; also elsewhere on the board
L_switch: SW2.2; also elsewhere on the board
unnamed: Ra1.5, U5.1 (ADDR)
unnamed: C1.2, L3.1, Ra1.4, U5.3 (GND)
unnamed: C1.1, L4.2, Ra1.6, Ra1.7, Ra1.8, U5.8 (VDD)
R_eje_x: U2.2, U5.7 (AIN3)
R_eje_y: U2.8, U5.6 (AIN2)
adc_alert: Ra1.1, U5.2 (ALERT/RDY); also elsewhere on the board
oled_scl: Ra1.2, U5.10 (SCL); also elsewhere on the board
oled_sda: Ra1.3, U5.9 (SDA); also elsewhere on the board
r_joy_sw: U2.4; also elsewhere on the board
r_switch: SW3.2; also elsewhere on the board

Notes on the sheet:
<----- C2
<----- RA1
https://learn.adafruit.com/assets/36145
Dirección IC: 0x49 -> a vcc 0x48 -> a gnd
u5 --->
l4 ----->
<--- C1
l3 ----->


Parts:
U4: EC11

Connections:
GND: U4.2 (GND), U4.5; also elsewhere on the board
enc_A: U4.1 (A); also elsewhere on the board
enc_B: U4.3 (B); also elsewhere on the board
enc_sw: U4.4; also elsewhere on the board


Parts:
BZ1: Buzzer_12x9.5RM7.6
C3: 100nF; C_0805_2012Metric_Pad1.18x1.45mm_HandSolder
R4: 68; R_0805_2012Metric

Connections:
GND: BZ1.2 (-), C3.2; also elsewhere on the board
unnamed: BZ1.1 (+), C3.1, R4.1
buzzer: R4.2; also elsewhere on the board

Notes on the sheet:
filtro pasa-bajo -->


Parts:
J1: NRF24L01; PinHeader_2x04_P2.54mm_Vertical

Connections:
+3V3: J1.2; also elsewhere on the board
/NRF24L01/irq: J1.8
GND: J1.1; also elsewhere on the board
nrf_ce: J1.3; also elsewhere on the board
nrf_cns: J1.4; also elsewhere on the board
nrf_miso: J1.7; also elsewhere on the board
nrf_mosi: J1.6; also elsewhere on the board
nrf_sck: J1.5; also elsewhere on the board


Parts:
C11: 10uF; C_1206_3216Metric_Pad1.33x1.80mm_HandSolder
C12, C16: 3.3nF; C_0805_2012Metric_Pad1.18x1.45mm_HandSolder
C14, C17: 22uF; C_0805_2012Metric_Pad1.18x1.45mm_HandSolder
C15: 10uF; C_0805_2012Metric_Pad1.18x1.45mm_HandSolder
D2, D3: SS54BF-HF; D_SMB_Handsoldering
J4: Barrel_Jack_Switch; POWER_JACK_SLOT
L1, L2: 2.2uH; L_Taiyo-Yuden_NR-50xx_HandSoldering
R1, R11: 100k; R_0805_2012Metric_Pad1.20x1.40mm_HandSolder
SW1: SS12D10
U9: TPS62143; QFN-16-1EP_3x3mm_P0.5mm_EP1.7x1.7mm
U11: TPS62142; QFN-16-1EP_3x3mm_P0.5mm_EP1.7x1.7mm

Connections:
+3V3: C17.1, L2.2, R11.1, U11.14 (VOS); also elsewhere on the board
+5F: C14.1, D3.2 (A), L1.2, R1.1, U9.14 (VOS)
+5V: C15.1, D2.1 (K), D3.1 (K), U11.10 (AVIN), U11.11 (PVIN), U11.12 (PVIN), U11.13 (EN); also elsewhere on the board
+5VP: D2.2 (A); also elsewhere on the board
+9V: C11.1, SW1.3, U9.10 (AVIN), U9.11 (PVIN), U9.12 (PVIN), U9.13 (EN)
GND: C11.2, C12.2, C14.2, C15.2, C16.2, C17.2, J4.2, J4.3, U9.5 (FB), U9.6 (AGND), U9.7 (FSW), U9.8 (DEF), U9.15 (PGND), U9.16 (PGND), U9.17 (PGND), U11.5 (FB), U11.6 (AGND), U11.7 (FSW), U11.8 (DEF), U11.15 (PGND), U11.16 (PGND), U11.17 (PGND); also elsewhere on the board
unnamed: J4.1, SW1.1, SW1.2
unnamed: L1.1, U9.1 (SW), U9.2 (SW), U9.3 (SW)
unnamed: L2.1, U11.1 (SW), U11.2 (SW), U11.3 (SW)
unnamed: R1.2, U9.4 (PG)
unnamed: C12.1, U9.9 (SS/TR)
unnamed: R11.2, U11.4 (PG)
unnamed: C16.1, U11.9 (SS/TR)

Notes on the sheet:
5V TPS62143
5V General
FA 5v
FA 3.3v
^-- por comodidad en la PCB
5V Arduino
1uF / 25V (grm31mf51e105za01L)

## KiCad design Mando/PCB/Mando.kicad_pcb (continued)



Board: 2 copper layers, 155.0 x 79.1 mm, 36 parts (3 on the bottom side), 39 nets.

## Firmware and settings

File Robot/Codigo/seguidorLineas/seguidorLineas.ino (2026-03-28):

// plaquita: Arduino mega 2560

#include "src/Motores/Motores.h"
#include "src/sensoresLineas/sensoresLineas.h"

int8_t direccion_robot = 0; // -1 derecha, 0 recto, 1 izquierda

#define RECTO 0
#define DERECHA 1
#define IZQUIERDA 2

bool centrado = true;
uint8_t sentido = RECTO;

void setup()
{
  Serial.begin(9600);

  motores_init();
  sensoresLinias_init();

  delay(100);
  sensoresLinias_polling();

  adelante();
  // Serial.println("adelante");
}

void loop()
{
  sensoresLinias_polling();

  // -------------------------------- sensores interiores
  if (sensorCentralL_isActive() || sensorCentralR_isActive())
  {
    centrado = true;
  }

  // -------------------------------- sensores exteriores
  if (sensor_izq_isActive())
  {
    sentido = DERECHA;
    centrado = false;
    izquierda();
  }

  if (sensor_der_isActive())
  {
    sentido = IZQUIERDA;
    centrado = false;
    derecha();
  }

  // -------------------------------- extra ( cuando se logró centrar al robot )
  if (centrado)
  {
    switch (sentido)
    {
    case IZQUIERDA:
      if (sensorCentralL_isActive())
      {
        sentido = DERECHA;
        izquierda();
      }
      break;

    case DERECHA:
      if (sensorCentralR_isActive())
      {
        sentido = IZQUIERDA;
        derecha();
      }
      break;

    default:
      sentido = RECTO;
      adelante();
      break;
    }
  }
}

// -------------------------------- Sensores

// -------------------------------- Motor
void adelante()
{
  motor_runProporcional(MOTOR_IZQUIERDO, 104);
  motor_runProporcional(MOTOR_DERECHO, 85);
}

void izquierda()
{
  motor_runProporcional(MOTOR_IZQUIERDO, 90);
  motor_runProporcional(MOTOR_DERECHO, 85);
}

void derecha()
{
  motor_runProporcional(MOTOR_IZQUIERDO, 104);
  motor_runProporcional(MOTOR_DERECHO, 90);
}

void detenido()
{
  motor_runProporcional(MOTOR_IZQUIERDO, 90);
  motor_runProporcional(MOTOR_DERECHO, 90);
}

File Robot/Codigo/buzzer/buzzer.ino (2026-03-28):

// plaquita: Arduino mega 2560

#include "src/Buzzer/Buzzer.h"
#include "src/Pulsadores/Pulsadores.h"

void setup()
{
  Serial.begin(9600);

  buzzer_init();
  pulsadores_init();
}

void loop()
{
  buzzer_polling();
  pulsadores_polling();

  if (isUpClicked())
  {
    buzzer_play_startup();
  }

  if (isCenterClicked())
  {
    buzzer_play_error();
  }

  if (isDownClicked())
  {
    buzzer_play_success();
  }
}

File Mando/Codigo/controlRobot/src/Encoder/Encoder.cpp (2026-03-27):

#include "Encoder.h"

// Variables estáticas para el encoder
static encoder_state_t encoder = {
    .position = 0,
    .lastPosition = 0,
    .lastEncoded = 0,
    .lastDebounceTime = 0,
    .changed = false};

// Variables estáticas para el pulsador
static encoder_switch_t encoderSwitch = {
    .pressed = false,
    .lastPressed = false,
    .clicked = false,
    .lastDebounceTime = 0
    //
};

// Constante para detección de presión prolongada (ms)
static const unsigned long HOLD_TIME_MS = 1000;

// Tabla de estados para decodificación del encoder
// Esta tabla mapea las transiciones de los estados (A, B)
// Formato: estado anterior (bits 2-3) y estado actual (bits 0-1)
// Retorna: -1 = giro antihorario, 0 = sin cambio, 1 = giro horario
static const int8_t encoderStates[] = {
    0,  // 0000 (0)
    -1, // 0001 (1) - Antihorario
    1,  // 0010 (2) - Horario
    0,  // 0011 (3)
    1,  // 0100 (4) - Horario
    0,  // 0101 (5)
    0,  // 0110 (6)
    -1, // 0111 (7) - Antihorario
    -1, // 1000 (8) - Antihorario
    0,  // 1001 (9)
    0,  // 1010 (10)
    1,  // 1011 (11) - Horario
    0,  // 1100 (12)
    1,  // 1101 (13) - Horario
    -1, // 1110 (14) - Antihorario
    0   // 1111 (15)
};

// Función de interrupción
void encoder_handleInterrupt(void)
{
    unsigned long currentTime = millis();

    // Debounce para evitar lecturas erróneas
    if ((currentTime - encoder.lastDebounceTime) < ENCODER_DEBOUNCE_DELAY_MS)
    {
        return;
    }
    encoder.lastDebounceTime = currentTime;

    // Leer estados actuales de los pines A y B
    uint8_t stateA = digitalRead(ENCODER_PIN_A);
    uint8_t stateB = digitalRead(ENCODER_PIN_B);

    // Codificar estado actual (bits: bit0 = A, bit1 = B)
    uint8_t currentState = (stateA << 1) | stateB;

    // Combinar estado anterior (bits 2-3) con estado actual (bits 0-1)
    uint8_t combinedState = (encoder.lastEncoded << 2) | currentState;

    // Obtener cambio de la tabla
    int8_t change = encoderStates[combinedState];

    // Actualizar posición si hay cambio
    if (change != 0)
    {
        encoder.position += change;
        encoder.changed = true;
    }

    // Guardar estado actual para próxima interrupción
    encoder.lastEncoded = currentState;
}

void encoder_init(void)
{
    // Configurar pines del encoder
    pinMode(ENCODER_PIN_A, INPUT_PULLUP);
    pinMode(ENCODER_PIN_B, INPUT_PULLUP);
    pinMode(ENCODER_PIN_SW, INPUT_PULLUP);

    // Leer estado inicial
    uint8_t stateA = digitalRead(ENCODER_PIN_A);
    uint8_t stateB = digitalRead(ENCODER_PIN_B);
    encoder.lastEncoded = (stateA << 1) | stateB;
    encoder.position = 0;
    encoder.lastPosition = 0;
    encoder.changed = false;

    // Configurar interrupciones para ambos pines
    // En Arduino Nano: pin 2 = INT0, pin 3 = INT1
    attachInterrupt(digitalPinToInterrupt(ENCODER_PIN_A), encoder_handleInterrupt, CHANGE);
    attachInterrupt(digitalPinToInterrupt(ENCODER_PIN_B), encoder_handleInterrupt, CHANGE);
}

void encoder_polling(void)
{
    unsigned long currentTime = millis();

    // Leer estado actual del pulsador (LOW = presionado por pull-up)
    bool currentPressed = (digitalRead(ENCODER_PIN_SW) == LOW);

    // Debounce
    if (currentPressed != encoderSwitch.lastPressed)
    {
        encoderSwitch.lastDebounceTime = currentTime;
    }

    if ((currentTime - encoderSwitch.lastDebounceTime) > ENCODER_SW_DEBOUNCE_MS)
    {
        // Solo actualizar si el estado es diferente al actual
        if (currentPressed != encoderSwitch.pressed)
        {
            // Detectar flanco de subida (cuando se suelta el pulsador)
            // Si estaba presionado y ahora no, es un click
            if (encoderSwitch.pressed == true && currentPressed == false)
            {
                encoderSwitch.clicked = true;
            }

            // Actualizar estado
            encoderSwitch.pressed = currentPressed;
        }
    }

    // Guardar último estado para debounce
    encoderSwitch.lastPressed = currentPressed;
}

void encoder_reset(void)
{
    noInterrupts(); // Deshabilitar interrupciones temporalmente
    encoder.position = 0;
    encoder.changed = true;
    interrupts(); // Rehabilitar interrupciones
}

int32_t encoder_getPosition(void)
{
    int32_t pos;
    noInterrupts(); // Leer variable volátil de forma segura
    pos = encoder.position;
    interrupts();
    return pos;
}

int32_t encoder_getDelta(void)
{
    int32_t delta;
    noInterrupts();
    delta = encoder.position - encoder.lastPosition;
    encoder.lastPosition = encoder.position;
    interrupts();
    return delta;
}

bool encoder_hasChanged(void)
{
    bool changed;
    noInterrupts();
    changed = encoder.changed;
    encoder.changed = false; // Resetear flag después de leer
    interrupts();
    return changed;
}

bool encoder_isTurning(void)
{
    // Verifica si ha habido cambio en la última lectura
    return encoder_hasChanged();
}

// Funciones para el pulsador
bool encoder_switch_isPressed(void)
{
    return encoderSwitch.pressed;
}

bool encoder_switch_isClicked(void)
{
    bool clicked = encoderSwitch.clicked;
    encoderSwitch.clicked = false; // Resetear flag después de leer
    return clicked;
}

bool encoder_switch_isHeld(void)
{
    static unsigned long pressStartTime = 0;
    static bool wasPressed = false;

    if (encoderSwitch.pressed && !wasPressed)
    {
        // Acaba de presionarse
        pressStartTime = millis();
    }

    wasPressed = encoderSwitch.pressed;

    // Retorna true si está presionado por más de HOLD_TIME_MS
    return (encoderSwitch.pressed &&
            (millis() - pressStartTime) > HOLD_TIME_MS);
}

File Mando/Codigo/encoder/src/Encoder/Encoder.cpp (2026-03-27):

#include "Encoder.h"
#include <limits.h>

// -----------------------------------------------------------------------------
// Estado del encoder
// -----------------------------------------------------------------------------
static encoder_state_t encoder = {
    .position = 0,
    .lastPosition = 0,
    .lastEncoded = 0,
    .lastDebounceTime = 0,
    .changed = false};

// -----------------------------------------------------------------------------
// Estado del pulsador
// -----------------------------------------------------------------------------
static encoder_switch_t encoderSwitch = {
    .pressed = false,
    .lastPressed = false,
    .clicked = false,
    .lastDebounceTime = 0};

// -----------------------------------------------------------------------------
// Constantes
// -----------------------------------------------------------------------------
static const unsigned long HOLD_TIME_MS = 1000;

// Tabla de estados (Gray code)
static const int8_t encoderStates[16] = {
    0, -1, 1, 0,
    1, 0, 0, -1,
    -1, 0, 0, 1,
    0, 1, -1, 0};

// -----------------------------------------------------------------------------
// ISR del encoder
// -----------------------------------------------------------------------------
void encoder_handleInterrupt(void)
{
    unsigned long currentTime = millis();

    // Debounce básico
    if ((currentTime - encoder.lastDebounceTime) < ENCODER_DEBOUNCE_DELAY_MS)
        return;

    encoder.lastDebounceTime = currentTime;

    uint8_t stateA = digitalRead(ENCODER_PIN_A);
    uint8_t stateB = digitalRead(ENCODER_PIN_B);

    uint8_t currentState = (stateA << 1) | stateB;
    uint8_t combinedState = (encoder.lastEncoded << 2) | currentState;

    int8_t change = encoderStates[combinedState];

    // 🔁 INVERTIR SENTIDO DEL GIRO
    change = -change;

    if (change != 0)
    {
        // Saturación INT8
        if (!((encoder.position == INT8_MAX && change > 0) ||
              (encoder.position == INT8_MIN && change < 0)))
        {
            encoder.position += change;
        }
        encoder.changed = true;
    }

    encoder.lastEncoded = currentState;
}

// -----------------------------------------------------------------------------
// Inicialización
// -----------------------------------------------------------------------------
void encoder_init(void)
{
    pinMode(ENCODER_PIN_A, INPUT_PULLUP);
    pinMode(ENCODER_PIN_B, INPUT_PULLUP);
    pinMode(ENCODER_PIN_SW, INPUT_PULLUP);

    uint8_t stateA = digitalRead(ENCODER_PIN_A);
    uint8_t stateB = digitalRead(ENCODER_PIN_B);

    encoder.lastEncoded = (stateA << 1) | stateB;
    encoder.position = 0;
    encoder.lastPosition = 0;
    encoder.changed = false;

    attachInterrupt(digitalPinToInterrupt(ENCODER_PIN_A),
                    encoder_handleInterrupt, CHANGE);
    attachInterrupt(digitalPinToInterrupt(ENCODER_PIN_B),
                    encoder_handleInterrupt, CHANGE);
}

// -----------------------------------------------------------------------------
// Polling del pulsador
// -----------------------------------------------------------------------------
void encoder_polling(void)
{
    unsigned long currentTime = millis();
    bool currentPressed = (digitalRead(ENCODER_PIN_SW) == LOW);

    if (currentPressed != encoderSwitch.lastPressed)
        encoderSwitch.lastDebounceTime = currentTime;

    if ((currentTime - encoderSwitch.lastDebounceTime) > ENCODER_SW_DEBOUNCE_MS)
    {
        if (currentPressed != encoderSwitch.pressed)
        {
            if (encoderSwitch.pressed && !currentPressed)
                encoderSwitch.clicked = true;

            encoderSwitch.pressed = currentPressed;
        }
    }

    encoderSwitch.lastPressed = currentPressed;
}

// -----------------------------------------------------------------------------
// Utilidades
// -----------------------------------------------------------------------------
void encoder_reset(void)
{
    noInterrupts();
    encoder.position = 0;
    encoder.changed = true;
    interrupts();
}

int8_t encoder_getPosition(void)
{
    int8_t pos;
    noInterrupts();
    pos = encoder.position;
    interrupts();
    return pos;
}

int8_t encoder_getDelta(void)
{
    int8_t delta;
    noInterrupts();
    delta = encoder.position - encoder.lastPosition;
    encoder.lastPosition = encoder.position;
    interrupts();
    return delta;
}

bool encoder_hasChanged(void)
{
    bool changed;
    noInterrupts();
    changed = encoder.changed;
    encoder.changed = false;
    interrupts();
    return changed;
}

bool encoder_isTurning(void)
{
    return encoder_hasChanged();
}

// -----------------------------------------------------------------------------
// Pulsador
// -----------------------------------------------------------------------------
bool encoder_switch_isPressed(void)
{
    return encoderSwitch.pressed;
}

bool encoder_switch_isClicked(void)
{
    bool clicked = encoderSwitch.clicked;
    encoderSwitch.clicked = false;
    return clicked;
}

bool encoder_switch_isHeld(void)
{
    static unsigned long pressStartTime = 0;
    static bool wasPressed = false;

    if (encoderSwitch.pressed && !wasPressed)
        pressStartTime = millis();

    wasPressed = encoderSwitch.pressed;

    return (encoderSwitch.pressed &&
            (millis() - pressStartTime) > HOLD_TIME_MS);
}

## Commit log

2026-03-26 [Added] PCB del mando
    [Displays.kicad_sch, FA.kicad_sch, JST - XH - Thru - 2Pin - 2.5mm (Genuine).stp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]
2026-03-26 [Added] 3D del mando
    [mando.FCStd]
2026-03-27 [Added] Ejemplos de codigo para el mando del robot
2026-03-27 [Added] 3D robot
    [3DChunbot.FCStd]
2026-03-27 [Added] PCB robot
    [7segment.step, Arduino.kicad_sch, Arduino_Mega_2560.step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]
2026-03-27 [Modified] Cambio serigrafia para soporte de sensor de temperatura TMP36
    [PCB_ChunBot.kicad_pcb]
2026-03-28 [Added] Codigos de ejemplo del robot
2026-04-02 [Improved] Inicializacion serial para ver mensajes del modulo de radio
